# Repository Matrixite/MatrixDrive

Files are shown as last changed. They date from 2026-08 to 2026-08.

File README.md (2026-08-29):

# MatrixDrive



MatrixDrive started with a simple idea: make a Mega Drive/Genesis cartridge
that you can plug into a computer with USB-C, copy a game onto like a flash
drive, and then use in a real console.

Revision B takes that idea quite a bit further. It is also designed to run
Master System software on compatible Mega Drive hardware, supply ROM data to a
real 32X, work in the upper slot of Sonic & Knuckles, and keep supported save
data in battery-free FRAM.

- [Download the current source and prebuilt firmware package](https://github.com/Matrixite/MatrixDrive/raw/refs/heads/main/MatrixDrive_Dual_System_Cart_RevB_LockOn_Codemasters_64K_FRAM.zip)
- [Download the standalone KiCad project](https://github.com/Matrixite/MatrixDrive/raw/refs/heads/main/MatrixDrive_RevB_KiCad_Project.zip)

> [!IMPORTANT]
> MatrixDrive is still an engineering prototype. The software and logic have
> been tested, and the PCB has a preliminary fully connected route, but no
> physical cartridge has been built or tested in a console. Several package pin
> assignments still need to be verified and the board has not passed KiCad DRC.
> Please do not send the current PCB straight to a manufacturer.

## What MatrixDrive can do

| Mode | Files | Maximum size | What happens |
| --- | --- | ---: | --- |
| Mega Drive / Genesis | `.BIN`, `.MD`, `.GEN` | 4 MiB | The game is presented as linear cartridge ROM |
| 32X with real 32X hardware | `.32X` | 4 MiB | MatrixDrive supplies the ROM while the real 32X provides the 32X hardware |
| Sonic & Knuckles upper slot | Mega Drive images | 2 MiB recommended | Supports Sonic 2 lock-on and Sonic 3 with its dedicated save area |
| Master System | `.SMS` | 2 MiB | Uses either the Sega or Codemasters mapper selected by SW4 |

Master System mode should work on standard Mega Drive/Genesis Model 1 and Model
2 consoles. It will not work on an unmodified Genesis 3 or Sega Nomad because
their cartridge-port Master System mode pin is disconnected. The JVC X'Eye can
run SMS cartridges through an adapter, but its reset circuit prevents SMS games
from running from a Genesis flash cartridge such as MatrixDrive. Compatibility
with other all-in-one, portable, licensed, or clone systems has not yet been
verified. MatrixDrive also does not fit a standalone Master System cartridge
slot, and SMS mode cannot run through a 32X or the Sonic & Knuckles upper slot.

## How it works

When MatrixDrive is connected to a computer, it appears as a FAT16 drive called
`MATRIXDRV`. The RP2350B checks the game image and programs it into parallel NOR
flash. After USB is disconnected, the CPLD takes over and responds to the
console immediately, without waiting for the microcontroller to boot.

The main hardware is:

- an RP2350B for USB, file handling, validation, and flash programming;
- 32-Mbit x16 parallel NOR flash for predictable cartridge ROM reads;
- an ATF1508ASV CPLD for mode selection, address decoding, and SMS mapping;
- level translators and bus isolation for the 5 V console and 3.3 V logic;
- two FRAM devices providing 64 KiB of battery-free SMS save storage;
- a separate FRAM for the 8 KiB Sonic 3 lock-on save window;
- USB/console power isolation, status LEDs, SWD/UART, and test points.

## Loading a game

1. Remove MatrixDrive from the console, 32X, or lock-on cartridge.
2. Connect it to your computer with USB-C.
3. Open the `MATRIXDRV` drive, delete the old game, and copy over one supported
   image.
4. Safely eject the drive and wait for the green completion light.
5. Disconnect USB completely.
6. With all power off, select MD or SMS with SW2 and choose the required profile
   with SW4.
7. Insert the cartridge, then power on the console.

> [!WARNING]
> Never connect USB while MatrixDrive is fitted to a console, 32X, or Sonic &
> Knuckles cartridge. Never move SW2 or SW4 while powered, and never hot-plug any
> part of the cartridge stack.

## Switch settings

SW4 changes purpose depending on the position of SW2:

| SW2 | SW4 low | SW4 high |
| --- | --- | --- |
| MD | Linear ROM, 32X, or Sonic 2 lock-on | Linear ROM with Sonic 3 save FRAM |
| SMS | Sega mapper | Codemasters mapper |

Always change these switches with USB and console power disconnected.

## Sonic & Knuckles lock-on

For **Sonic 2 & Knuckles**, copy a normal Sonic 2 image, set SW2 to **MD**, and
set SW4 low to **LINEAR**. Power-of-two images up to 2 MiB are mirrored across
the upper-cartridge ROM window.

For **Sonic 3 & Knuckles**, copy a normal Sonic 3 image, set SW2 to **MD**, and
set SW4 high to **S3 SAVE**. MatrixDrive then maps the dedicated save FRAM over
odd-byte addresses `$200001-$203FFF` while leaving the rest of the ROM visible.

Read [Sonic & Knuckles lock-on mode](MatrixDrive_Dual_System_Cart_RevB/docs/sonic-knuckles-lock-on.md)
for the exact mapping, switch positions, and physical-fit checks.

## Using a real 32X

MatrixDrive is not trying to reproduce a 32X. A real 32X still supplies its
processors, boot ROM, registers, video, and audio hardware; MatrixDrive only
supplies the cartridge ROM.

Copy a `.32X` image, set SW2 to **MD**, leave SW4 low, disconnect USB, and fit
MatrixDrive to an unpowered 32X. The installer checks the `SEGA` header and
`MARS CHECK MODE` marker before accepting the image.

Do not use SW4 high for 32X software because that setting deliberately replaces
part of the ROM address range with the Sonic 3 save window. More detail is in
[32X cartridge mode](MatrixDrive_Dual_System_Cart_RevB/docs/32x-mode.md).

## Master System mapping and saves

| Profile | Mapper writes | Starting ROM banks | Save window |
| --- | --- | --- | --- |
| Sega | `$FFFC-$FFFF` | 0, 1, 2 | 16 KiB at `$8000-$BFFF` |
| Codemasters | `$0000`, `$4000`, `$8000` | 0, 1, 0 | 8 KiB at `$A000-$BFFF` |

In Codemasters mode, bit 7 of the `$4000` write enables FRAM and bits 2:0 choose
one of eight 8 KiB banks. This makes all 64 KiB of SMS save storage available
without hiding the ROM at `$8000-$9FFF`.

See [Master System mode](MatrixDrive_Dual_System_Cart_RevB/docs/master-system-mode.md)
for the full register and banking behaviour.

## Supported image rules

- Mega Drive/Genesis images must be normal big-endian ROMs, contain `SEGA` at
  offset `0x100`, and fit within 4 MiB.
- 32X images must use `.32X`, contain `SEGA` at `0x100` and `MARS CHECK MODE` at
  `0x3C0`, be a multiple of four bytes, and fit within 4 MiB.
- Lock-on images should be even-sized powers of two no larger than 2 MiB.
- Headerless SMS images need `TMR SEGA` at `0x1FF0`, `0x3FF0`, or `0x7FF0`.
- Interleaved `.SMD` files and copier headers are not supported.
- Only use game images that you are legally entitled to use.

No commercial ROM images are included in this repository.

## What has been tested

The project is automatically rebuilt and tested on every change. The passing
software-only tests currently cover:

- the FAT16 USB drive and ROM installer;
- Mega Drive, Master System, and 32X image validation;
- simulated NOR programming and ROM mirroring;
- Sega and Codemasters SMS mapper behaviour;
- Codemasters FRAM enabling and all eight save banks;
- Sonic 2/Sonic 3 lock-on mapping and the Sonic 3 save decoder;
- CPLD RTL simulation for MD, SMS, 32X ROM access, and lock-on modes;
- a complete RP2350B firmware build;
- a two-ROM emulator test that reached the combined Sonic 3 & Knuckles title
  screen and opening sequence.

These tests show that the intended software and logic paths behave correctly.
They cannot prove cartridge fit, signal timing, voltage translation, power
isolation, save retention, or operation on real Sega hardware.

## PCB status

The KiCad project contains a complete logical schematic and a preliminary
eight-layer PCB route. The routing report currently records all 188 routable
nets connected, using six signal layers plus dedicated ground and 3.3 V planes.

Before a board can be considered ready to build, it still needs:

- verified physical pin assignments and manufacturer footprints for the
  RP2350B, CPLD, NOR, translators, and FRAM devices;
- CPLD fitting, resource checks, and worst-case timing analysis;
- KiCad ERC/DRC after refilling the copper zones;
- USB differential-pair and signal/power-integrity review;
- cartridge-edge, PCB-thickness, bevel, shell, and insertion measurements;
- staged bench testing before it is connected to any console.

Only the Sonic 3 odd-byte save layout is implemented for Mega Drive software.
Generic Mega Drive or 32X SRAM/EEPROM saves, ROMs larger than 4 MiB,
enhancement hardware, unusual regional or game-specific SMS mappers, light-gun
support, and Sega mapper RAM-at-`$C000` mode are outside this revision.

Start with [Safety and bring-up](MatrixDrive_Dual_System_Cart_RevB/docs/safety-and-bringup.md)
before attempting any hardware test.

## Project layout

| Path | What you will find there |
| --- | --- |
| [`MatrixDrive_Dual_System_Cart_RevB/`](MatrixDrive_Dual_System_Cart_RevB/) | Main Revision B project |
| [`cpld/`](MatrixDrive_Dual_System_Cart_RevB/cpld/) | Mapper RTL, reference model, and testbench |
| [`firmware/`](MatrixDrive_Dual_System_Cart_RevB/firmware/) | RP2350B USB installer firmware |
| [`hardware/`](MatrixDrive_Dual_System_Cart_RevB/hardware/) | KiCad files, BOM, pinout, netlist, and routing report |
| [`docs/`](MatrixDrive_Dual_System_Cart_RevB/docs/) | Architecture, compatibility, and bring-up notes |
| [`tools/`](MatrixDrive_Dual_System_Cart_RevB/tools/) | Project generator, router, and validation scripts |

The [full design README](MatrixDrive_Dual_System_Cart_RevB/README.md) contains
the component-level details and additional design notes.

## Building and testing the project

You will need Python 3, the Raspberry Pi Pico SDK 2.3.0, an Arm GNU toolchain,
CMake/Ninja, and Icarus Verilog.

```sh
cd MatrixDrive_Dual_System_Cart_RevB
python3 tools/generate_kicad_project.py
python3 tools/route_kicad_pcb.py
python3 tools/validate_project.py
```

To build the RP2350B firmware:

```sh
export PICO_SDK_PATH=/absolute/path/to/pico-sdk
cmake -S firmware -B ../build/firmware -G Ninja \
  -DPICO_BOARD=matrixdrive \
  -DPICO_PLATFORM=rp2350-arm-s \
  -DCMAKE_BUILD_TYPE=Release
cmake --build ../build/firmware
```

## Technical references

- [Genesis Plus GX cartridge implementation](https://github.com/ekeeke/Genesis-Plus-GX/blob/master/core/cart_hw/md_cart.c)
- [Sega 32X Hardware Manual transcription](https://github.com/matiaszanolli/sega-vr-disasm/blob/master/docs/32x-hardware-manual.md)
- [Raspberry Pi RP2350 documentation](https://www.raspberrypi.com/documentation/microcontrollers/microcontroller-chips.html)
- [Microchip ATF1508ASV](https://www.microchip.com/en-us/product/atf1508asv)
- [Infineon FM18W08 FRAM](https://www.infineon.com/part/FM18W08-SG)
- [TI SN74LVC1T45](https://www.ti.com/product/SN74LVC1T45)

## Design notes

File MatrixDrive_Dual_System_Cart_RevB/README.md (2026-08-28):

# MatrixDrive Dual-System USB Cartridge — Revision B

MatrixDrive Revision B is a prototype USB-loadable Mega Drive/Genesis cartridge that can also supply ROM to a real 32X, run Master System software on compatible consoles, and act as the upper cartridge in Sonic & Knuckles lock-on mode. USB-C exposes a removable FAT16 drive named `MATRIXDRV`; after one ROM is copied and safely ejected, the RP2350B installs it into non-volatile parallel NOR.

Console reads never depend on RP2350 response time. Translators and an instant-on CPLD connect the console directly to NOR or the selected FRAM.

## Supported images

| Console mode | File | Active image limit | Cartridge hardware |
| --- | --- | ---: | --- |
| Mega Drive / Genesis | `.BIN`, `.MD`, `.GEN` | 4 MiB | Linear `$000000-$3FFFFF` ROM |
| 32X through a real 32X | `.32X` | 4 MiB | Linear x16 ROM with 4 MiB mask-ROM-style mirroring |
| Sonic & Knuckles upper slot | Mega Drive image | 2 MiB recommended | Mirrored ROM; optional Sonic 3 save profile |
| Master System | `.SMS` | 2 MiB | Sega or Codemasters mapper selected by SW4 |

Power-of-two Mega Drive images smaller than 2 MiB are repeated by the installer through the full 2 MiB lock-on window. This gives a 1 MiB Sonic 2 image the mirroring expected from its original mask ROM.

Power-of-two `.32X` images smaller than 4 MiB are repeated through the complete 32-Mbit cartridge space. The firmware requires the standard `SEGA` header at `0x100` and `MARS CHECK MODE` at `0x3C0`, then preserves every ROM byte—including the mandatory 32X security/startup area beginning at `0x3F0`.

For Sonic 3 & Knuckles, SW4's high position in MD mode enables a dedicated 8 KiB odd-byte FRAM window at `$200001-$203FFF`. This storage is physically separate from the two FM18W08 devices that supply the complete 64 KiB SMS save array.

SMS images are stored one byte per x16 NOR word. The CPLD implements Sega or Codemasters 16 KiB banking selected by SW4. Plain 8/16/32/48 KiB images and larger mapped images work.

## Normal use

1. Remove MatrixDrive from the console, 32X, or Sonic & Knuckles cartridge.
2. Connect USB-C, remove the previous image, and copy one supported ROM to `MATRIXDRV`.
3. Safely eject and wait for the steady green completion indication.
4. Disconnect USB and set SW2/SW4 while all hardware is unpowered.
5. Insert MatrixDrive directly into the console, into the real 32X cartridge slot for `.32X` use, or into the Sonic & Knuckles upper slot for MD lock-on use.
6. Power on. In SMS mode, use the cartridge PAUSE button when a game needs the Master System NMI pause input.

### Switch positions

| Use | SW2 | SW4 |
| --- | --- | --- |
| Normal Mega Drive or Sonic 2 & Knuckles | MD | Low: LINEAR |
| 32X cartridge through real 32X hardware | MD | Low: LINEAR |
| Sonic 3 & Knuckles with saves | MD | High: S3 SAVE |
| Sega-mapper SMS | SMS | Low: SEGA |
| Codemasters-mapper SMS | SMS | High: CODEMASTERS |

Never move either switch while powered. Never connect USB while MatrixDrive is inserted into a console, 32X, or another cartridge.

## 32X compatibility

MatrixDrive does not emulate a 32X. In this mode, the physical 32X supplies its dual SH2 processors, boot ROM, registers, video and audio hardware, while MatrixDrive behaves as the attached 4 MiB cartridge ROM. The 32X adapter performs its normal cartridge banking internally.

Use SW2=MD and SW4=LINEAR. SW4's S3 SAVE position is not compatible because it intentionally replaces odd-byte addresses `$200001-$203FFF` with FRAM. Generic 32X SRAM/EEPROM saves, images larger than 4 MiB, and special cartridge hardware are not implemented.

See `docs/32x-mode.md` for exact mapping and real-hardware bring-up requirements.

## Lock-on compatibility

The electrical profile follows the documented lock-on behaviour and the Genesis Plus GX implementation:

- Sonic & Knuckles supplies its own ROM at the lower 2 MiB and exposes the upper cartridge in the remaining window.
- MatrixDrive behaves as a normal MD ROM in the upper slot.
- The installer supplies mask-ROM-style mirroring for even-sized power-of-two images up to 2 MiB.
- The Sonic 3 save profile maps U20 to odd-byte addresses `$200001-$203FFF`.
- U19 translates the CPLD's high-byte-disable request into the 5 V domain so U7 is inactive during low-byte-only save cycles.
- Sonic & Knuckles owns its `$A130F0` lock-on control; MatrixDrive does not emulate the base lock-on cartridge.

See `docs/sonic-knuckles-lock-on.md` for exact use and remaining physical-fit validation.

## Image validation

- Mega Drive images require `SEGA` at byte offset `0x100`, normal big-endian byte order, and a maximum size of 4 MiB. Interleaved `.SMD` images are rejected.
- `.32X` images must be a multiple of four bytes, fit in 4 MiB, contain `SEGA` at `0x100`, and contain `MARS CHECK MODE` at `0x3C0`.
- Lock-on images should be even-sized powers of two no larger than 2 MiB.
- Headerless SMS images require `TMR SEGA` at `0x1FF0`, `0x3FF0`, or `0x7FF0`.
- Use only software you are legally entitled to use.

## Hardware summary

- RP2350B, USB Full-Speed Mass Storage, and a 16 MiB FAT16 staging flash.
- S29GL032N-compatible 32-Mbit x16 active parallel NOR.
- ATF1508ASV-15AU100 CPLD for instant-on mode, SMS mapping, and Sonic 3 save decode.
- U17/U18: two FM18W08 32 KiB x8 FRAMs, exactly 64 KiB for SMS saves.
- U20: dedicated FM18W08, with 8 KiB decoded for Sonic 3 lock-on saves.
- U19: SN74LVC1T45 translating the MD high-data-disable control to CART_5V.
- Dual-supply 5 V/3.3 V translation on every active cartridge signal.
- USB/console source isolation, PROGRAM and PAUSE buttons, and power-off selectors.

## Project contents

- `docs/architecture.md` — electrical and data-path architecture.
- `docs/master-system-mode.md` — SMS mapper and storage details.
- `docs/32x-mode.md` — real-32X cartridge mapping, switches, limits, and bring-up.
- `docs/sonic-knuckles-lock-on.md` — lock-on mapping, switches, fit, and limitations.
- `docs/safety-and-bringup.md` — mandatory staged test procedure.
- `hardware/bom.csv`, `connector-pinout.csv`, `electrical-netlist.csv` — connection authorities.
- `hardware/MatrixDrive-RevB.sch` — complete logical schematic; KiCad 8/9 converts it to native format on first save.
- `hardware/MatrixDrive-RevB.kicad_pcb` — native preliminary routed eight-layer PCB with the physical cartridge edge, six signal layers, and dedicated ground/3.3 V planes.
- `hardware/routing-report.json` — deterministic route completion counts, layer assignment, widths, and via dimensions.
- `hardware/README-KICAD.md` — project opening instructions and fabrication release gates.
- `cpld/matrixdrive_mapper.v` — synthesizable SMS and lock-on decoder RTL.
- `cpld/test_matrixdrive_mapper.v` — RTL mapper/FRAM testbench.
- `firmware/` — RP2350/Pico SDK firmware source.

## Engineering status

This is a **Revision B engineering prototype**, not a fabrication-ready or production-tested commercial cartridge. The PCB has a preliminary connectivity-complete route, but it has not passed KiCad DRC or physical review. Before fabrication, review and verify the logical schematic, assign and fit the CPLD, verify resources and timing, copy the official RP2350B minimal design, confirm exact package pin maps, review/refine the route, pass ERC/DRC, and measure the edge/shell against a normal donor cartridge, a real 32X cartridge slot, and a real Sonic & Knuckles upper slot.

Do not send the included KiCad PCB directly to fabrication. Complete the release gates in `hardware/README-KICAD.md` and `docs/safety-and-bringup.md` before any console test.

The repository root also contains `MatrixDrive_RevB_KiCad_Project.zip`, a
standalone copy of the schematic, board, symbol library, BOM and connection
authorities.

## Build prerequisites

- Raspberry Pi Pico SDK 2.3.0 and Arm GNU Toolchain.
- CMake plus Ninja or Make.
- Icarus Verilog for RTL simulation.
- KiCad 8 or later for schematic conversion, PCB editing, ERC and DRC.
- A verified ATF1508ASV fitting/JED programming flow.

The prototype USB descriptor uses TinyUSB's development VID `0xCAFE`. Obtain a proper VID/PID before distribution.

## Primary references

- Genesis Plus GX MD cartridge: <https://github.com/ekeeke/Genesis-Plus-GX/blob/master/core/cart_hw/md_cart.c>
- Genesis Plus GX SRAM: <https://github.com/ekeeke/Genesis-Plus-GX/blob/master/core/cart_hw/sram.c>
- Sega 32X Hardware Manual transcription: <https://github.com/matiaszanolli/sega-vr-disasm/blob/master/docs/32x-hardware-manual.md>
- TI SN74LVC1T45: <https://www.ti.com/product/SN74LVC1T45>
- RP2350: <https://www.raspberrypi.com/documentation/microcontrollers/microcontroller-chips.html>
- ATF1508ASV: <https://www.microchip.com/en-us/product/atf1508asv>
- FM18W08 FRAM: <https://www.infineon.com/part/FM18W08-SG>

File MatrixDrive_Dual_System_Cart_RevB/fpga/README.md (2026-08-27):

# Master System YM2413 FPGA option

This directory implements the optional MatrixDrive Master System FM path. It
adds a dedicated Lattice ECP5 FPGA beside the existing ATF1508 mapper; the
CPLD remains responsible for ROM and save mapping, while the FPGA implements
the YM2413, its I/O ports and the audio DAC.

This is an RTL-complete engineering option, not a retrofit for an assembled
Revision B PCB. The Revision B placement template has no FPGA, configuration
flash, FPGA power rails or audio filter. Integrate the logical netlist here
into a reviewed schematic and routed board spin before building hardware.

## Implemented behavior

| SMS port | Direction | FPGA behavior |
| --- | --- | --- |
| `F0` | Write | Latches the YM2413 register address |
| `F1` | Write | Writes data to the selected YM2413 register |
| `F2` | Read/write | Three-bit FM/detection register; reset read is `FF` |

F2 bit 0 enables the cartridge FM output. Bits 1 and 2 are stored and read
back for software compatibility. Bit 1 cannot mute the Mega Drive's internal
PSG from a cartridge, so software that relies on hardware PSG suppression may
sound different.

Every port decode includes `/IORQ`. In Mega Drive SMS mode, VA19 on the edge
connector becomes the Master System `/IORQ`; MatrixDrive already translates
that pin onto the `CART_A18` net. The FPGA top-level therefore receives it as
`cart_a18_iorq_n`. Do not replace this with address-only decoding.

## RTL data path

1. `sms_fm_bus.v` synchronizes F0/F1/F2 writes from the cartridge bus and
   generates clean write pulses for the OPLL core.
2. The BSD-licensed IKAOPLL core implements the cycle-accurate YM2413 signal
   path and produces a signed 16-bit accumulated sample.
3. `pdm_dac.v` converts that sample to a 14.31818 MHz one-bit stream.
4. A two-pole passive low-pass filter, AC coupling capacitor and separate
   injection resistors feed cartridge audio inputs SL1 and SR2.

The data bus is driven only for an F2 I/O read while SMS mode is selected and
USB is absent. It is high-impedance for normal memory cycles, MD mode and USB
programming.

## Clock and target

The reference target is `LFE5U-12F-6BG256C`. The top-level input is a dedicated
14.318180 MHz CMOS oscillator. A one-in-four clock enable supplies the OPLL
with the 3.579545 MHz phiM rate while all FPGA registers stay in one physical
clock domain.

Generic ECP5 synthesis reports approximately 1,347 LUT4s, 1,727 flip-flops,
103 carry cells and two 18x18 multipliers. This leaves substantial margin in a
12K device. Final utilization and timing must be rechecked after package-pin,
I/O-standard and board constraints are assigned.

For PAL pitch locked to the console's slower SMS clock, populate the
region-specific oscillator and change the top-level divide ratio/constraint
accordingly. The supplied 14.318180 MHz option intentionally produces the
original 3.579545 MHz YM2413 reference rate.

## Build and test

From this directory:

```sh
make test
make lint
make synth
```

`make test` needs Python 3 and Icarus Verilog. `make lint` and `make synth`
need Yosys with ECP5 support. Synthesis creates
`build/matrixdrive_sms_fm.json`.

The repository deliberately does not include a place-and-route constraint
file or bitstream. Package pins depend on the final schematic and PCB escape;
using invented assignments would be unsafe. Complete
`hardware/pin-assignment-template.csv`, add an LPF constraint file, run
nextpnr-ecp5, and close timing before programming a device.

## Hardware release gates

- Capture the FPGA, 1.1 V core, 2.5 V auxiliary, 3.3 V I/O/configuration and
  SPI-flash circuits from current Lattice reference documents.
- Recalculate the cartridge current budget and replace the existing 200 mA
  protection/regulator arrangement if measurements require it.
- Prove all FPGA pins are high-impedance during configuration, MD mode and USB
  programming. Add external gating if the chosen configuration mode cannot
  guarantee this.
- Scope VA19, `/LWR`, `/CAS0`, address and data on each supported console
  revision before relying on the timing assumptions.
- Verify the F2 read turnaround with U6 and prove NOR/FRAM output enables stay
  inactive during the I/O cycle.
- Measure the filtered output for DC, peak voltage and ultrasonic residue
  before connecting SL1/SR2. Tune the two injection resistors on real hardware.
- Validate with the YM2413 test ROM and several FM-capable games on NTSC and
  PAL console revisions.

See `hardware/fpga-addon-bom.csv`, `hardware/logical-netlist.csv` and
`hardware/pin-assignment-template.csv` for the schematic-level integration
authority.

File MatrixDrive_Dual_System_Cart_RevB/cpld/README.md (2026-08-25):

# CPLD logic

`matrixdrive_mapper.v` is the portable logic source for U13. It contains the
instant-on Mega Drive/32X linear pass-through, Sega SMS mapper, Codemasters SMS mapper,
64 KiB FRAM decode, and USB ownership isolation. No console transaction depends
on the RP2350.

The power-off SW4 selector drives `codemasters_mapper` low for Sega or high for
Codemasters. Sega writes are decoded only at `$FFFC-$FFFF`. Codemasters writes
are decoded only at `$0000`, `$4000`, and `$8000`; bit 7 of the `$4000`
value enables an 8 KiB FRAM window at `$A000-$BFFF`, with bits 2:0 selecting
one of eight FRAM banks.

Target: `ATF1508ASV-15AU100`, 3.3 V, TQFP-100. The device has 128
macrocells, but fit and timing are release gates. This prototype intentionally
does not include guessed package pin assignments. Create them only after
schematic placement so voltage, JTAG, clock-capable pins, output-enable
resources, routing and timing can be reviewed together.

Required flow before hardware release:

1. Import/translate the module into the selected ATF1508ASV-supported tool.
2. Assign every port to the reviewed U13 schematic symbol and JTAG header.
3. Constrain translated address/control input-to-memory output delays.
4. Confirm the device fits and archive equations, fitter report, timing report,
   JED file and checksum.
5. Run `python3 test_mapper_model.py` and the Icarus RTL testbench.
   The RTL test includes the highest word address in the 4 MiB 32X cartridge
   space as well as the SMS and Sonic 3 save profiles.
6. Simulate the fitted equations and test a programmed device on a
   current-limited cartridge-slot breakout.

The USB-mode tri-states require external inactive pulls on NOR/FRAM controls
and FRAM address lines A13/A14. Do not rely on CPLD power-up values for bus
safety.

Device page: <https://www.microchip.com/en-us/product/atf1508asv>

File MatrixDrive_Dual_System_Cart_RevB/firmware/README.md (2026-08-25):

# Firmware

The firmware uses the Raspberry Pi Pico C/C++ SDK and TinyUSB. It targets the
RP2350B package because the parallel ROM bus consumes GPIO0 through GPIO39 and
the QFN-80 device supplies GPIO40 through GPIO47 for staging flash, sensing and
indicators.

## Build

```sh
export PICO_SDK_PATH=/absolute/path/to/pico-sdk
cmake -S . -B build -DPICO_BOARD=matrixdrive
cmake --build build
```

The output is `build/matrixdrive.uf2` plus ELF, BIN and HEX files. Fit the board's
SWD header for the first load; later firmware can also be loaded through the
RP2350 boot ROM when the hardware exposes its boot-select condition.

## Source layout

- `main.c` selects console-safe or USB programming operation.
- `msc_disk.c` implements the TinyUSB Mass Storage callbacks.
- `spi_nor.c` provides a 4 KiB cached block device on the staging flash.
- `fat16.c` formats and scans the staging volume without a dynamic allocator.
- `parallel_nor.c` programs and verifies the S29GL032N-compatible active ROM.
- `rom_installer.c` validates and streams a selected ROM into the active flash,
  packing MD/32X images x16 and SMS images one byte per word. Explicit `.32X`
  files also require the standard header/security marker and are mirrored
  through the complete 4 MiB cartridge range when appropriate.
- `usb_descriptors.c` defines a single Full-Speed MSC interface.

## Important implementation note

This is first-pass prototype firmware and has not been executed on the custom
board. Compile warnings should be treated as errors, and the active-NOR command
set must be checked against the exact suffix of the fitted flash before running
an erase or program operation. Keep the hardware write-enable pullup fitted
during all early tests. Firmware does not move the physical MD/SMS switch; set
SW2 only while the board is unpowered.

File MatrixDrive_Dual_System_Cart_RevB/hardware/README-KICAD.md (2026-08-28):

# MatrixDrive Revision B KiCad project

This directory now contains a complete logical engineering capture for the
MatrixDrive cartridge and a native KiCad 8 PCB with the same component and net
model.

## Open the project

1. Open `MatrixDrive-RevB.sch` in KiCad 8 or 9 Eeschema.
2. Accept KiCad's conversion prompt, then save it as
   `MatrixDrive-RevB.kicad_sch` beside the existing project file.
3. Open `MatrixDrive-RevB.kicad_pcb` in PCB Editor.
4. Refill all zones with `B`, then run **Inspect > Design Rules Checker**. Do
   not waive errors until the logical footprints below have been replaced.

The schematic is supplied in KiCad's readable legacy format because the
automated build environment does not contain Eeschema. `MatrixDrive_RevB.lib`
and `sym-lib-table` make the custom logical symbols self-contained. The board
file and `MatrixDrive-RevB.kicad_pro` are native KiCad 8 files.

## Captured circuitry

- 64-contact Mega Drive/Genesis cartridge edge and every used signal;
- USB-C UFP power, CC resistors, ESD protection and USB data path;
- diode-OR power isolation, fuse, 3.3 V regulator and RP2350 support rails;
- RP2350B GPIO mapping, boot QSPI, staging SPI flash, SWD/UART and indicators;
- 32-Mbit x16 active NOR ROM;
- five address/control translators, two data translators and isolation logic;
- ATF1508ASV mapper interface, JTAG and all RTL-visible signals;
- Sega/Codemasters SMS mapper controls and 64 KiB FRAM;
- Sonic 3 lock-on save FRAM and upper-byte disable path;
- MD/SMS, Pause and profile switches plus open-drain cartridge controls;
- pull-ups, pull-downs, decoupling and 22 named diagnostic test points.

The generated model currently contains 143 component references, 777 logical
pins and 192 named nets. `kicad-project-manifest.json` records these counts and
the outstanding release gates.

## PCB status

The PCB has the 100 mm x 65 mm engineering outline, physical 2x32 cartridge
edge, all component references, assigned pad nets, preliminary placement and a
connectivity-complete deterministic route. The eight-layer stack uses F.Cu,
In2.Cu, In3.Cu, In4.Cu, In5.Cu and B.Cu for signals, with uninterrupted GND on
In1.Cu and 3V3 on In6.Cu. `routing-report.json` records 188 of 188 routable nets
complete, 3,917 segments and 1,246 vias.

This route is a DRC handoff, not a fabrication release. It has not been opened
or checked by KiCad in the automated environment, USB is not yet
length/impedance controlled, and no signal-integrity or power-integrity review
has been done.

The programmable-device and memory symbols use logical, alphanumeric pad names
until the exact physical package maps have been approved. Those footprints are
marked `UNVERIFIED` or `LOGICAL`. They prevent this engineering capture from
being mistaken for a fabrication-ready board.

Before fabrication:

1. replace the U1, U2, U13, translator and FRAM logical footprints with verified
   manufacturer/package footprints;
2. assign and fit every ATF1508ASV pin, then close CPLD timing;
3. copy the current official RP2350B minimal-design power and QSPI pin mapping;
4. confirm NOR reset, write-protect and byte-mode strap polarity;
5. review/refine the preliminary bus route and route USB as a controlled 90-ohm differential pair;
6. review power integrity, translator direction/OE timing and cartridge loading;
7. refill zones and pass KiCad ERC, DRC and connectivity inspection;
8. complete the staged checks in `../docs/safety-and-bringup.md`.

Do not order PCBs from the generated board in its current state.

## Regeneration

Run:

```sh
python3 tools/generate_kicad_project.py
python3 tools/route_kicad_pcb.py
```

The older `generate_kicad_pcb.py` command is retained as a compatibility
wrapper and generates the same complete project.

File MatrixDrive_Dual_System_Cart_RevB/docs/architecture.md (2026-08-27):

# Architecture

## Console data paths

The console does not read through the RP2350. Translators convert the 5 V cartridge bus to 3.3 V, and the instant-on CPLD selects ROM or FRAM.

```text
MD/32X mode:  cartridge bus -> translators -> CPLD -> x16 NOR
S3 save:      odd byte  -> low translator -> CPLD -> dedicated x8 FRAM
SMS mode:     Z80 bus   -> translators -> CPLD mapper -> NOR low byte
                                      write/save tap -> 2 x x8 SMS FRAM
SMS FM spin:  VA19 /IORQ + F0/F1/F2 -> ECP5 YM2413 -> PDM filter -> SL1/SR2
USB mode:     USB-C -> RP2350B -> staging SPI NOR -> active parallel NOR
```

`hardware/electrical-netlist.csv` is the signal connection authority. This description is not a substitute for a reviewed schematic.

## Power and isolation

- Edge contacts A2/A31 feed `CART_5V` through F1; USB VBUS is separate.
- D1 and D2 diode-OR the sources into `SYS_5V`; U11 produces `3V3`.
- Cartridge-facing translator ports use `CART_5V` and become high impedance during USB-only operation.
- `BUS_DISABLE` is forced high when USB VBUS and console power coexist.
- `USB_MODE_3V3` tells U13 to release all shared NOR and FRAM controls.
- ROM and every FRAM chip enable have passive inactive pullups.
- U19 uses VCCA=3V3, VCCB=CART_5V, fixed A-to-B direction, Ioff, and VCC isolation to carry the Sonic 3 high-byte-disable request safely into U15.
- Both gates in U15 are used: the first combines bus/SMS isolation and the second adds the MD odd-byte save-cycle request.

## Mega Drive and lock-on mode

With SW2 in MD, `/M3`, VA21, and VA22 float. U13 normally passes translated VA1-VA21 to NOR A0-A20, `/CE_0` to `/CE`, and `/CAS0` to `/OE`. The x16 path returns VD0-VD15.

SW4 low selects the ordinary linear profile. It is also the Sonic 2 lock-on profile. Firmware repeats even-sized power-of-two MD images smaller than 2 MiB until the 2 MiB upper-cartridge window is filled.

SW4 high selects the Sonic 3 save profile:

- CPU odd-byte addresses `$200001-$203FFF` correspond to word addresses `$100000-$101FFF` on `cart_a`.
- U13 disables NOR and selects U20 only inside that range while `/CE_0` is active.
- U20 A0-A12 follow the cartridge word address; A13/A14 are grounded.
- `/CAS0` and `/LWR` become the shared FRAM OE/WE strobes.
- `md_high_disable` passes through U19 and U15 to disable U7, preventing the unused high byte from being driven during x8 FRAM access.
- U17/U18 remain inactive, keeping all 64 KiB of SMS save storage separate.

Sonic & Knuckles owns its `$A130F0` mapping control and supplies the lower cartridge ROM. MatrixDrive behaves only as the normal cartridge inserted in the upper slot.

## 32X cartridge mode

A physical 32X reads its inserted cartridge from both the Mega Drive/Genesis
68000 side and the SH2 side. The adapter owns its bank register and bus
arbitration; MatrixDrive remains a simple x16 ROM.

With SW2=MD and SW4=LINEAR, U13 passes the complete 21-bit word address to the
4 MiB NOR. The highest cartridge byte pair at `$3FFFFE-$3FFFFF` is word address
`$1FFFFF`. The 32X startup/security area is stored byte-for-byte and is not
interpreted by the CPLD.

SW4=S3 SAVE must not be used with 32X images because it replaces part of the
linear ROM range with U20. See `32x-mode.md`.

## Master System mode

With power off, SW2 is moved to SMS. Open-drain FETs pull `/M3`, VA21, and VA22 low. U13 then:

- uses translated VA1-VA16 as Z80 A0-A15;
- observes mapper writes through the low-byte bidirectional translator;
- maps three 16 KiB ROM slots using the SW4 profile;
- decodes Sega writes at `$FFFC-$FFFF` or exact Codemasters writes at `$0000/$4000/$8000`;
- uses `/CE_0` for `$0000-$7FFF` and `/CAS2` for `$8000-$BFFF`;
- drives only VD0-VD7;
- decodes 32 KiB Sega saves or banked 64 KiB Codemasters saves.

SW3 pulls the PAUSE/NMI contact low through an open-drain FET. See `master-system-mode.md`.

The optional FPGA spin taps translated A0-A7, D0-D7, `/LWR`, `/CAS0`, reset,
SMS/USB mode, and `CART_A18`. VA19 becomes `/IORQ` only in SMS mode, so
`CART_A18` is the mandatory I/O-cycle qualifier. The ECP5 never participates
in ROM or save mapping and drives MEM_D0-D7 only for an exact F2 I/O read.

The FPGA uses a dedicated 14.318180 MHz oscillator, a one-in-four phiM clock
enable, the IKAOPLL YM2413 core, and a one-bit PDM output. A passive two-pole
filter plus DC blocking and left/right series resistors inject mono FM into
SL1 and SR2. The FPGA option's separate logical connection authority is
`../fpga/hardware/logical-netlist.csv`.

## USB storage and installation

The RP2350 QSPI flash is dedicated to firmware. A separate 16 MiB SPI NOR backs a FAT16 superfloppy named `MATRIXDRV`. On safe eject, firmware validates one image, erases active NOR, and verifies each programmed word.

- MD bytes are packed big-endian: bytes 0/1 become flash D15:8/D7:0.
- 32X images use the same big-endian x16 packing; smaller power-of-two images repeat through 4 MiB.
- Even-sized power-of-two MD images below 2 MiB repeat through the 2 MiB lock-on window.
- SMS bytes use one x16 word each: D15:8 is `0xFF` and D7:0 is the ROM byte.

The same 4 MiB x16 NOR therefore holds either 4 MiB of MD/32X data or 2 MiB of SMS byte data.

## Programming ownership

RP2350 GPIO0-GPIO39 share the NOR-side bus and remain inputs without USB. With USB present, U13 releases shared outputs and the cartridge translators isolate before firmware drives those GPIOs. External pulls hold NOR, U17, U18, and U20 inactive during reset and handover. The RP2350 does not currently expose FRAM contents through USB.

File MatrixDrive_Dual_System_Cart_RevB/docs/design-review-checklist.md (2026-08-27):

# Design review checklist before routing

Revision B intentionally stops before a fabrication release. Close every item
below in the final schematic and PCB review.

## RP2350B subsystem

- Import the **current RP2350B Minimal KiCad** reference from Raspberry Pi's
  Product Information Portal; do not redraw the on-chip buck regulator from
  memory.
- Copy the complete VREG, DVDD/1V1, IOVDD, ADC_AVDD, USB_OTP_VDD, RUN, crystal,
  boot-flash and decoupling circuits.
- Preserve the official inductor orientation, output-capacitor placement and
  current return path. Use the specified polarised Abracon inductor unless the
  current hardware guide approves a substitute.
- Confirm every QFN-80 power and ground pin plus the exposed pad.
- Confirm external QSPI routing and boot-straps for the exact W25Q16 package.
- Run the latest Pico SDK board-header checks with `PICO_RP2350A=0`.

Official source: <https://pip.raspberrypi.com/categories/1214-rp2350>

## Cartridge interface

- Compare all 64 pad numbers with a known-good donor PCB and continuity-test a
  cartridge-slot breakout.
- Confirm that the KiCad front copper is the console-facing B row and back copper
  is the A row for the selected physical orientation.
- Verify hard-gold thickness, 1.6 mm board thickness, edge bevel and insertion
  depth with the intended manufacturer.
- Measure insertion, removal, door travel, component clearance and contact wipe
  in a real 32X cartridge slot as well as direct-console and lock-on slots.
- Simulate or measure 90 ns NOR access plus translator and CPLD delay against
  `/CE_0`, `/CAS0`, and `/CAS2` at minimum and maximum supply voltage.
- Capture real 32X SH2/68000 cartridge read timing at low and high ROM addresses
  and confirm the adapter's wait states cover the complete data-path delay.
- Confirm translator DIR straps and `BUS_DISABLE` default state with both power
  sources in every sequence.
- Fit an ATF1508ASV programming coupon first, assign all TQFP-100 pins, and
  archive the compiler fit/timing report and programmed JED checksum.
- Prove CPLD outputs release before RP2350 programming ownership and that
  passive pulls keep NOR/FRAM `/CE`, `/OE`, and `/WE` inactive during reset.
- Verify SW2 is break-before-make and asserts `/M3`, VA21 and VA22 through
  open-drain devices only; never source 3.3 V into those cartridge nets.
- Verify SW4 is labelled SEGA/CODEMASTERS, is sampled as a 3.3 V CPLD input,
  and cannot float during break-before-make travel.
- Measure U16/U6 direction turnaround around `/LWR` and prove the console, NOR,
  either FRAM and translator never drive D7:D0 simultaneously.
- Verify U17/U18 never assert together and exercise all eight Codemasters 8 KiB
  FRAM banks through logical addresses `$0000-$FFFF`.
- Check unused console inputs are not accidentally driven.

## Optional YM2413 FPGA spin

- Complete every item in `../fpga/README.md`; Revision B cannot be retrofitted
  merely by loading FPGA RTL.
- Capture the current ECP5 power, sysCONFIG, JTAG, oscillator and decoupling
  circuits in the reviewed schematic. Do not assign package pins from the
  logical template without completing BGA escape and bank-voltage review.
- Constrain the 14.318180 MHz clock, run place-and-route, close timing, archive
  the exact bitstream hash, and verify configuration completes safely.
- Prove ECP5 bus pins are high-impedance while unconfigured, in MD mode, with
  USB present, and during all non-F2 cycles.
- Scope VA19 as `/IORQ` on every intended console revision and verify F0/F1
  writes and F2 reads/writes cannot collide with NOR or FRAM.
- Recalculate the 3.3 V rail, 1.1 V/2.5 V regulators, inrush and cartridge
  fuse from post-route power estimates and measured current.
- Measure the PDM filter response, DC leakage, ultrasonic residue and peak
  voltage before fitting SL1/SR2 injection resistors.
- Run a YM2413 diagnostic and FM-capable games, including rhythm mode and F2
  enable/disable behavior, on NTSC and PAL targets.

## USB and power

- Route D+/D- as a short 90-ohm differential pair over an uninterrupted ground
  reference, with the ESD device at the receptacle.
- Verify separate 5.1 kOhm Rd resistors on CC1 and CC2.
- Measure reverse leakage through both source-isolation diodes.
- Verify the resettable fuse value against measured console-mode current.
- Prove that USB-only operation leaves A2/A31 and every other edge contact
  unpowered/high impedance.

## Storage and firmware

- Confirm the exact staging-flash JEDEC ID or relax the whitelist only after
  testing a substitute.
- Power-cycle during writes to evaluate FAT and erase-cache recovery.
- Test Windows, macOS and Linux safe-eject behaviour.
- Test fragmented files and root directories containing unrelated files.
- Test minimum, maximum, odd-length and invalid-header images.
- Test `.32X` images at 1, 2 and 4 MiB, invalid `MARS CHECK MODE` data, and the
  highest byte pair at `$3FFFFE-$3FFFFF`.
- Test `.SMS` images at 8 KiB, 32 KiB, 48 KiB and 2 MiB in both SW4 positions.
- Exercise every Sega register, the fixed 1 KiB window, both Sega FRAM halves,
  all three Codemasters bank registers and all eight Codemasters FRAM banks.
- Reserve a real USB VID/PID before any public product release.

## Release gates

- ERC clean with reviewed exceptions.
- DRC clean with a documented manufacturer rule set.
- Four-layer stack-up and impedance quotation approved.
- Current-limited breakout test passed.
- Logic-analyser timing capture archived.
- At least one Model 1 and one Model 2 console tested with homebrew diagnostics.
- Real 32X tested with a ROM-only diagnostic, followed by multiple legally
  obtained cartridge images covering different ROM sizes and regions.
- Master System mode tested on each intended console revision, including reset,
  Pause NMI and a save/load/power-cycle cycle.

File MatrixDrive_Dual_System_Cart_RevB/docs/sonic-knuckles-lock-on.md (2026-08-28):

# Sonic & Knuckles lock-on mode

## Scope

MatrixDrive is designed to behave as the ordinary Mega Drive/Genesis cartridge inserted into the upper slot of an original Sonic & Knuckles cartridge. It does not replace or emulate the Sonic & Knuckles base cartridge.

This profile targets:

- Sonic 2 & Knuckles from a normal Sonic 2 image;
- Sonic 3 & Knuckles from a normal Sonic 3 image;
- the normal Blue Sphere response that Sonic & Knuckles produces for other simple ROM cartridges.

SMS mode, unusual MD mappers, serial EEPROM cartridges, enhancement hardware, and carts larger than 2 MiB are not supported through the lock-on path in this revision.

## Why ROM mirroring is required

Sonic & Knuckles exposes the upper cartridge in a 2 MiB window. A physical small mask ROM naturally repeats when unimplemented high address pins are absent. MatrixDrive uses a 4 MiB NOR, so firmware must reproduce that behaviour.

During installation, an MD image is repeated through 2 MiB when all of these are true:

- the file is smaller than 2 MiB;
- its size is a power of two;
- its size is even;
- it has passed the normal MD header validation.

A normal 1 MiB Sonic 2 image is therefore written twice. A 2 MiB Sonic 3 image needs no extra copy. The original source file on `MATRIXDRV` is unchanged.

## Sonic 3 save window

Sonic 3 & Knuckles accesses the save memory from the upper cartridge at odd-byte addresses `$200001-$203FFF`. On the cartridge word-address bus this is `$100000-$101FFF`.

With SW2=MD and SW4 high:

| Signal or device | Behaviour |
| --- | --- |
| U2 NOR | Disabled inside the save window |
| U20 | Selected for exactly 8 KiB using A0-A12 |
| U17/U18 | Disabled; SMS saves remain separate |
| U6 low data | Carries D0-D7 reads and writes |
| U7 high data | Disabled by U13 → U19 → U15 |
| Read strobe | `/CAS0` drives shared FRAM `/OE` |
| Write strobe | `/LWR` drives shared FRAM `/WE` |

U20 is a 32 KiB FM18W08 for component consistency and availability, but A13/A14 are grounded and only 8 KiB is visible. Its remaining capacity is intentionally inaccessible.

## Switch settings

| Game/result | SW2 | SW4 |
| --- | --- | --- |
| Sonic 2 & Knuckles | MD | Low: LINEAR |
| Sonic 3 & Knuckles with save support | MD | High: S3 SAVE |
| Other simple lock-on cartridge / Blue Sphere | MD | Low: LINEAR |

SW4 remains the Sega/Codemasters selector when SW2 is in SMS mode. Move both switches only with console and USB power absent.

## Loading and stacking

1. Remove MatrixDrive from all console hardware.
2. Connect USB-C and install a legal, clean big-endian Sonic 2 or Sonic 3 image.
3. Safely eject, wait for the steady green indication, and disconnect USB.
4. Set SW2/SW4 using the table above.
5. Insert MatrixDrive fully into the Sonic & Knuckles upper slot without rocking it.
6. Insert Sonic & Knuckles into the powered-off console.
7. Power on.
8. Power off and remove the complete stack before reconnecting USB or moving a switch.

## Physical requirements

The electrical design uses the standard 64-contact Mega Drive/Genesis edge. Physical lock-on compatibility also depends on details that cannot be proven by the preliminary routed engineering layout:

- PCB thickness and bevel;
- finger plating, pitch, and insertion depth;
- board and shell width;
- component height below the upper-slot door;
- switch and USB-C clearance;
- retention and extraction forces.

Measure a real Sonic & Knuckles cartridge and a known-good upper cartridge before finalising the board outline and shell. Do not fabricate the current template as-is.

## Validation gates

Before connecting to Sonic & Knuckles:

- pass direct-console MD tests;
- verify the 2 MiB mirror pattern in NOR;
- sweep the U20 decode boundaries with a cartridge breakout;
- verify U7 is disabled during every U20 cycle;
- confirm U20 does not overlap U17/U18;
- fit and time the exact ATF1508ASV equations;
- confirm the complete stacked assembly is mechanically stable;
- monitor current on the first lock-on power-up.

Automated tests prove the source-level decode and installer pattern. They do not prove CPLD fit, analogue timing, connector wear, or real-cartridge operation.

## Primary implementation references

- [Genesis Plus GX Mega Drive cartridge and lock-on handling](https://github.com/ekeeke/Genesis-Plus-GX/blob/master/core/cart_hw/md_cart.c)
- [Genesis Plus GX backup RAM mapping](https://github.com/ekeeke/Genesis-Plus-GX/blob/master/core/cart_hw/sram.c)

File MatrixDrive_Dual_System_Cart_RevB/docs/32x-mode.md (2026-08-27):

# 32X cartridge mode

## Scope

MatrixDrive can supply a cartridge ROM to a physical Sega 32X. It does not
emulate the 32X: the real adapter still provides the two SH2 processors, boot
ROM, security check, registers, video hardware, audio hardware, and cartridge
arbitration.

The 32X hardware maps a 32-Mbit cartridge space and can read the cartridge from
both its SH2 side and the Mega Drive/Genesis 68000 side. MatrixDrive's existing
4 MiB x16 NOR and MD linear CPLD path match that cartridge-ROM width and size.

## Image installation

Use a clean, normal big-endian `.32X` image no larger than 4 MiB. The installer
requires:

- file size of at least `0x400` bytes and no more than 4,194,304 bytes;
- a size divisible by four, as required by the 32X startup data layout;
- `SEGA` at byte offset `0x100`;
- `MARS CHECK MODE` at byte offset `0x3C0`.

The last check distinguishes an explicit `.32X` image from an ordinary Mega
Drive image and protects against programming an image without the expected 32X
startup/security area. The firmware does not patch this data. Every source byte
is written to parallel NOR in its original order.

When a `.32X` image is an exact power of two smaller than 4 MiB, the installer
repeats it through the complete 4 MiB active NOR. This reproduces the way a
smaller mask ROM appears when the 32X drives address pins that the original ROM
did not implement.

## Switches and physical stack

| Item | Required setting |
| --- | --- |
| SW2 | MD |
| SW4 | Low: LINEAR |
| USB | Disconnected |
| Stack | MatrixDrive -> real 32X -> Mega Drive/Genesis |

SW4 high is not a 32X profile. In MD mode it enables the Sonic 3 odd-byte FRAM
window at `$200001-$203FFF`, which would replace part of the 32X ROM and prevent
correct operation.

Power off the complete stack before insertion or removal. Do not place Sonic &
Knuckles between MatrixDrive and the 32X. Do not connect USB while MatrixDrive is
inserted into the 32X.

## What is implemented

- Standard 4 MiB linear x16 cartridge ROM.
- Explicit `.32X` FAT16 discovery and validation.
- Byte-for-byte preservation of the 32X header and security/startup code.
- Full 4 MiB mirroring for smaller power-of-two images.
- CPLD pass-through through the highest cartridge word address (`$3FFFFE`).

## Limits

- No generic 32X SRAM or EEPROM save emulation.
- No ROM images larger than 4 MiB.
- No special mapper, coprocessor, or enhancement cartridge hardware.
- Physical fit, voltage levels, bus timing, boot/security completion, and game
  operation have not yet been measured on a real 32X.

Games that depend on unsupported cartridge save memory may boot but cannot be
expected to save correctly. Use a ROM-only diagnostic or game for the first
hardware test.

## First real-32X test

Complete the USB-only, simulated-console, and direct Mega Drive tests in
`safety-and-bringup.md` first.

1. Inspect and clean the MatrixDrive and 32X cartridge contacts.
2. Install a legally obtained, known-good ROM-only `.32X` diagnostic or game.
3. Verify SW2=MD and SW4=LINEAR with all power removed.
4. Insert MatrixDrive into the unpowered 32X, then install the 32X normally.
5. Power the stack through a current monitor and stop for abnormal current,
   heat, or out-of-rail signals.
6. Capture cartridge `/CE_0`, `/CAS0`, address, and data timing at the start,
   middle, and top of the ROM range.
7. Confirm the 32X security/startup sequence completes and the program reaches
   its first interactive screen.
8. Power off and remove the complete stack before reconnecting USB.

## References

- [Sega 32X Hardware Manual transcription](https://github.com/matiaszanolli/sega-vr-disasm/blob/master/docs/32x-hardware-manual.md)
- [32X ROM identification in file(1)](https://github.com/file/file/blob/master/magic/Magdir/console)

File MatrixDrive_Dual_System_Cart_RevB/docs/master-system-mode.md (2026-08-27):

# Master System mode

## Scope

Revision B targets Master System software running through a Mega Drive/Genesis
cartridge slot, similar to the electrical role of a Power Base Converter. It is
not a physical Master System cartridge and requires a console revision that
still exposes and supports SMS mode.

Implemented:

- 8/16/32/48 KiB fixed/no-mapper ROMs;
- Sega mapper ROMs through 2 MiB;
- Codemasters mapper ROMs through 2 MiB;
- power-off Sega/Codemasters mapper selector;
- 64 KiB non-volatile FRAM shared by both mapper profiles;
- physical Pause/NMI button;
- optional FPGA YM2413 with `F0`/`F1` writes, `F2` detection and cartridge audio output.

Not implemented: Korean, multicart or game-specific mappers;
light-gun accessory circuitry; Mega Drive save hardware; Sega mapper bit 4
RAM-at-`$C000` mode. These require a later verified CPLD profile.

The FM option requires a new board spin and is not present on the Revision B
placement template.

## Power-off mapper selector

SW4 selects the SMS mapper profile. Move it only when console and USB power are
absent.

| SW4 position | Mapper writes | Reset ROM banks | Save window |
| --- | --- | --- | --- |
| Sega | `$FFFC-$FFFF` | 0, 1, 2 | 16 KiB at `$8000-$BFFF` |
| Codemasters | exact `$0000`, `$4000`, `$8000` | 0, 1, 0 | 8 KiB at `$A000-$BFFF` |

The selector is a hardware input to U13. Firmware does not auto-detect the
mapper and console transactions never wait for the RP2350.

## Sega mapper

U13 resets the control register to `0` and the three ROM banks to 0, 1, and 2.
Writes are captured at the rising edge of translated `/LWR`:

| Address | Register | Effect |
| --- | --- | --- |
| `$FFFC` | control | bit 3 enables FRAM; bit 2 selects FRAM half |
| `$FFFD` | page 0 | ROM bank for `$0000-$3FFF`, except fixed first 1 KiB |
| `$FFFE` | page 1 | ROM bank for `$4000-$7FFF` |
| `$FFFF` | page 2 | ROM bank for `$8000-$BFFF` |

Only bank bits 6:0 reach NOR A20:A14, matching the 2 MiB `.SMS` limit. Sega
FRAM uses the lower 32 KiB of the installed 64 KiB: A13 follows the CPU
address, A14 follows control bit 2, and the low FRAM chip is selected.

## Codemasters mapper

U13 resets the three ROM banks to 0, 1, and 0. There is no Sega-style fixed
first-1-KiB window.

| Write address | Effect |
| --- | --- |
| `$0000` | Select 16 KiB ROM bank for `$0000-$3FFF` |
| `$4000`, bit 7 clear | Disable FRAM and select ROM bank for `$4000-$7FFF` |
| `$4000`, bit 7 set | Enable FRAM; bits 2:0 select one of eight 8 KiB banks |
| `$8000` | Select 16 KiB ROM bank for `$8000-$BFFF` |

When FRAM is enabled, only `$A000-$BFFF` is replaced. ROM remains readable at
`$8000-$9FFF`, and enabling FRAM preserves the previous slot-1 ROM bank. The
three FRAM bank bits become logical A15:A13. Two 32 KiB FM18W08 devices provide
the exact 64 KiB array; U13 drives separate active-low chip enables for the low
and high halves.

The Codemasters behaviour matches the reset and banking implementation in
[Genesis Plus GX](https://github.com/ekeeke/Genesis-Plus-GX/blob/master/core/cart_hw/sms_cart.c).

## FPGA YM2413 option

In SMS mode, Mega Drive cartridge edge signal VA19 becomes the Z80 `/IORQ`.
Revision B already translates VA19 as `CART_A18`; the FPGA spin taps that net
along with A0-A7, D0-D7, `/LWR`, `/CAS0`, reset and the mode signals.

| I/O port | Behavior |
| --- | --- |
| `F0` | Write YM2413 register address |
| `F1` | Write YM2413 register data |
| `F2` | Read/write the three-bit FM/detection register |

The F2 register resets to `111`; reads return `11111xxx`. Bit 0 enables FM
audio. Bits 1 and 2 are stored for compatibility, but a cartridge cannot mute
the Mega Drive's internal PSG, so bit 1 is not able to reproduce that system-
level function.

F0 and F1 are forwarded to the cycle-accurate IKAOPLL core. Its signed output
feeds a one-bit PDM DAC, a two-pole low-pass filter, AC coupling, and separate
SL1/SR2 injection resistors. The FPGA bus pins are high-impedance in MD mode,
with USB present, and on every cycle other than an exact F2 I/O read.

See `../fpga/README.md` for RTL, clocking, synthesis, licensing and hardware
release gates.

## NOR representation

The installer writes SMS byte `n` to NOR word address `n` as
`0xFF00 | byte`. In SMS mode only D7:D0 are returned to the console. In MD
mode the same device is read normally as an x16 array. Installing a ROM replaces
the previous active image but does not erase FRAM.

## Physical mode and pause

SW2 must be a break-before-make slide switch and may only be moved with console
and USB power absent. It supplies `SMS_MODE_3V3` to the CPLD and enables
open-drain pulls on `/M3`, VA21 and VA22. Never drive those 5 V cartridge nets
directly from 3.3 V logic.

SW3 drives VA23 only through open-drain Q4. It is ignored in MD mode. Mount all
controls where they cannot contact the cartridge shell or move during insertion.

## Timing constraints

The CPLD address mux plus translator plus NOR/FRAM access must fit the SMS read
and write windows at worst-case voltage and temperature. Archive fitted-CPLD
timing plus oscilloscope/logic-analyser captures for both mapper profiles,
FRAM reads/writes, reset defaults, selector states and Pause NMI.

For the FPGA spin, also archive captures of F0/F1/F2 I/O cycles showing VA19
`/IORQ`, `/LWR` or `/CAS0`, address, data and FPGA output enable. Verify F2
turnaround through U6, confirm NOR/FRAM remain inactive, and measure filtered
audio amplitude and ultrasonic residue at both SL1 and SR2.

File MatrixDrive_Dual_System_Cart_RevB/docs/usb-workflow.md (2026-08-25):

# USB workflow and indicators

## Drive behaviour

The staging volume appears as `MATRIXDRV`. It accepts one root-level `.BIN`,
`.MD`, `.GEN`, `.32X`, or `.SMS` file. Subdirectories, `.SMD`, copier-headered SMS
images and files for unsupported mappers are ignored or rejected.

After copying, use **Eject** or **Safely remove**. The cartridge remains powered
while the active flash is erased, repacked and verified. Wait for steady green
before unplugging. The staging copy remains until the PC deletes it.

The firmware uses the file extension to choose flash layout. The physical SW2
mode is deliberately not changed by USB software; set it to match the installed
image only after USB has been disconnected and before console power is applied.

## Image rules

| Format | Minimum | Maximum | Header check | Flash packing |
| --- | ---: | ---: | --- | --- |
| MD/GEN/BIN | 512 B | 4,194,304 B | `SEGA` at `0x100` | two bytes/x16 word |
| 32X | 1 KiB | 4,194,304 B | `SEGA` at `0x100`; `MARS CHECK MODE` at `0x3C0` | two bytes/x16 word |
| SMS | 8 KiB | 2,097,152 B | `TMR SEGA` at `0x1FF0`, `0x3FF0`, or `0x7FF0` | one byte/x16 word |

Odd MD images receive an `0xFF` low-byte pad. `.32X` images must be a multiple
of four bytes and retain their original security/startup area. Smaller
power-of-two `.32X` images repeat through the complete 4 MiB cartridge range.
SMS images must be headerless binary dumps. Extension alone cannot make an
unsupported mapper, save device, or enhancement cartridge compatible.

## LEDs

| State | Green | Amber | Red |
| --- | --- | --- | --- |
| USB drive mounted | slow blink | off | off |
| PC writing staging flash | off | fast blink | off |
| Erasing/programming active ROM | off | steady | off |
| Install and verification successful | steady | off | off |
| No supported ROM, wrong size, or bad header | off | off | two-blink code |
| Flash/program/verify failure | off | off | steady |

The PROGRAM button requests the same install after pending USB writes are
flushed. Do not press it while the operating system is copying data.

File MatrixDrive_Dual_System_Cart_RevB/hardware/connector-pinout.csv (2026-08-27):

Contact | Console signal | Direction at cartridge | Rev B connection | Notes
A1 | GND | Power | GND | Ground
A2 | +5V | Power | CART_5V_IN | Join A31 before fuse F1
A3 | VA8 | Input | ADDR_XCVR_A7 | Cart address bit 7
A4 | VA11 | Input | ADDR_XCVR_A10 | Cart address bit 10
A5 | VA7 | Input | ADDR_XCVR_A6 | Cart address bit 6
A6 | VA12 | Input | ADDR_XCVR_A11 | Cart address bit 11
A7 | VA6 | Input | ADDR_XCVR_A5 | Cart address bit 5
A8 | VA13 | Input | ADDR_XCVR_A12 | Cart address bit 12
A9 | VA5 | Input | ADDR_XCVR_A4 | Cart address bit 4
A10 | VA14 | Input | ADDR_XCVR_A13 | Cart address bit 13
A11 | VA4 | Input | ADDR_XCVR_A3 | Cart address bit 3
A12 | VA15 | Input | ADDR_XCVR_A14 | Cart address bit 14
A13 | VA3 | Input | ADDR_XCVR_A2 | Cart address bit 2
A14 | VA16 | Input | ADDR_XCVR_A15 | Cart address bit 15
A15 | VA2 | Input | ADDR_XCVR_A1 | Cart address bit 1
A16 | VA17 | Input | ADDR_XCVR_A16 | Cart address bit 16
A17 | VA1 | Input | ADDR_XCVR_A0 | Cart address bit 0
A18 | GND | Power | GND | Ground
A19 | VD7 | Bidirectional | DATA_LOW_XCVR_A7 | ROM/SMS data bit 7 and mapper write data
A20 | VD0 | Bidirectional | DATA_LOW_XCVR_A0 | ROM/SMS data bit 0 and mapper write data
A21 | VD8 | Bidirectional | DATA_HIGH_XCVR_A0 | MD data bit 8; U7 disabled in SMS and MD Sonic 3 FRAM cycles
A22 | VD6 | Bidirectional | DATA_LOW_XCVR_A6 | ROM/SMS data bit 6
A23 | VD1 | Bidirectional | DATA_LOW_XCVR_A1 | ROM/SMS data bit 1
A24 | VD9 | Bidirectional | DATA_HIGH_XCVR_A1 | MD data bit 9; U7 disabled in SMS and MD Sonic 3 FRAM cycles
A25 | VD5 | Bidirectional | DATA_LOW_XCVR_A5 | ROM/SMS data bit 5
A26 | VD2 | Bidirectional | DATA_LOW_XCVR_A2 | ROM/SMS data bit 2
A27 | VD10 | Bidirectional | DATA_HIGH_XCVR_A2 | MD data bit 10; U7 disabled in SMS and MD Sonic 3 FRAM cycles
A28 | VD4 | Bidirectional | DATA_LOW_XCVR_A4 | ROM/SMS data bit 4
A29 | VD3 | Bidirectional | DATA_LOW_XCVR_A3 | ROM/SMS data bit 3
A30 | VD11 | Bidirectional | DATA_HIGH_XCVR_A3 | MD data bit 11; U7 disabled in SMS and MD Sonic 3 FRAM cycles
A31 | +5V | Power | CART_5V_IN | Join A2 before fuse F1
A32 | GND | Power | GND | Ground
B1 | SL1 | Not used on Rev B | NC | Optional FPGA spin injects filtered AC-coupled FM audio
B2 | /MRES | Input | CTRL2_XCVR_MRES | CPLD asynchronous mapper reset
B3 | SR2 | Not used on Rev B | NC | Optional FPGA spin injects filtered AC-coupled FM audio
B4 | VA9 | Input | ADDR_XCVR_A8 | Cart address bit 8
B5 | VA10 | Input | ADDR_XCVR_A9 | Cart address bit 9
B6 | VA18 | Input | ADDR_XCVR_A17 | MD address bit 17
B7 | VA19 | Input | ADDR_XCVR_A18 | MD address bit 18; active-low IORQ in SMS mode and FPGA FM qualifier
B8 | VA20 | Input | ADDR_XCVR_A19 | MD address bit 19
B9 | VA21 | Bidirectional mode | ADDR_XCVR_A20 and Q2 drain | MD address bit 20; open-drain low in SMS mode
B10 | VA22 | Mode | Q3 drain | Open-drain low in SMS mode; floating in MD mode
B11 | VA23 | Pause | Q4 drain | Open-drain PAUSE/NMI pulse in SMS mode only
B12 | /YS | Not used | NC | Video signal
B13 | /VSYNC | Not used | NC | Video signal
B14 | /HSYNC | Not used | NC | Video signal
B15 | EDCLK | Not used | NC | Video clock
B16 | /CAS0 | Input | CTRL_XCVR_CAS0 | ROM plus SMS and Sonic 3 FRAM output-enable timing
B17 | /CE_0 | Input | CTRL_XCVR_CE0 | MD ROM CE and SMS slots 0/1 select
B18 | /AS | Input | CTRL2_XCVR_AS | Translated for diagnostics and future profiles
B19 | VCLK | Input | TP_VCLK | Test point only
B20 | /DTACK | Open drain/unused | NC | Console supplies timing for standard ROM
B21 | /CAS2 | Input | CTRL_XCVR_CAS2 | SMS slot 2 ROM/FRAM select
B22 | VD15 | Bidirectional | DATA_HIGH_XCVR_A7 | MD data bit 15; U7 disabled in SMS and MD Sonic 3 FRAM cycles
B23 | VD14 | Bidirectional | DATA_HIGH_XCVR_A6 | MD data bit 14; U7 disabled in SMS and MD Sonic 3 FRAM cycles
B24 | VD13 | Bidirectional | DATA_HIGH_XCVR_A5 | MD data bit 13; U7 disabled in SMS and MD Sonic 3 FRAM cycles
B25 | VD12 | Bidirectional | DATA_HIGH_XCVR_A4 | MD data bit 12; U7 disabled in SMS and MD Sonic 3 FRAM cycles
B26 | /ASEL | Input | NC | Not required
B27 | /VRES | Input | TP_VRES | Test point only
B28 | /LWR | Input | CTRL2_XCVR_LWR and U16 input | SMS writes and MD odd-byte Sonic 3 FRAM write strobe
B29 | /UWR | Input | CTRL2_XCVR_UWR | Translated for diagnostics; Sonic 3 FRAM is odd-byte only and uses /LWR
B30 | /M3 | Mode | Q1 drain | Open-drain low in SMS mode; floating in MD mode
B31 | /TIME | Input | CTRL2_XCVR_TIME | Translated for diagnostics; Sonic & Knuckles owns its $A130F0 lock-on control
B32 | /CART | Output | 0R to GND | Selects bootable cartridge mapping

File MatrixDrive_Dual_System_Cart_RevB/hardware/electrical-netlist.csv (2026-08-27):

Net | From | To | Direction or rule
CART_5V_IN | J1.A2 and J1.A31 | F1.1 | Join both edge power contacts
CART_5V | F1.2 | D1.A; U3-U8.VCCA/VCC as applicable; U14-U16.VCCA/VCC; U19.VCCB | Console-only 5V domain
USB_VBUS | J2.VBUS | D2.A; R5.1; R7.1; R29.1 | USB source plus two independent presence dividers
SYS_5V | D1.K and D2.K | U11.IN; C23.1 | Diode-ORed supply
3V3 | U11.OUT | U1/U2/U9/U10/U13/U17-U20 supplies; U3-U7/U14 VCCB; C decoupling | Digital 3.3V rail
GND | J1.A1/A18/A32; J2.GND; all IC grounds | Ground plane | Single continuous plane
USB_DP | J2.DP | R3.1 | Route 90ohm differential with USB_DM
USB_DP_MCU | R3.2 | U1.USB_DP | Short matched pair
USB_DM | J2.DM | R4.1 | Route 90ohm differential with USB_DP
USB_DM_MCU | R4.2 | U1.USB_DM | Short matched pair
USB_ESD | USB_DP; USB_DM | U12.IO1/IO2 | U12 beside J2 with short ground return
CC1 | J2.CC1 | R1.1 | R1.2 to GND
CC2 | J2.CC2 | R2.1 | R2.2 to GND
BUS_DISABLE | U8.Y | U3-U6./OE; U14./OE; U15.1A | Low enables console translation; USB with console present drives high
DATA_HIGH_BASE_DISABLE | U15.1Y | U15.2A | Logical BUS_DISABLE OR SMS_MODE_5V
MD_HIGH_DISABLE_3V3 | U13.md_high_disable | U19.A | High only during the Sonic 3 odd-byte FRAM window or USB coexistence
MD_HIGH_DISABLE_5V | U19.B | U15.2B | U19 translates the CPLD request into the CART_5V logic domain
DATA_HIGH_DISABLE | U15.2Y | U7./OE | High disables upper data byte for SMS USB coexistence or MD odd-byte FRAM
CART_A0-7 | U3.B0-B7 | U13.cart_a0-7; U17.A0-7; U18.A0-7; U20.A0-7 | U3 A-side from J1 VA1-VA8
CART_A8-12 | U4.B0-B4 | U13.cart_a8-12; U17.A8-12; U18.A8-12; U20.A8-12 | Translated address and FRAM 8 KiB window offset
CART_A13 | U4.B5 | U13.cart_a13 | Translated address; FRAM A13 is mapper-controlled
CART_A14-15 | U4.B6-B7 | U13.cart_a14-15 | Translated Z80/68000 address
CART_A16-20 | U5.B0-B4 | U13.cart_a16-20 | Translated MD address; A18 is VA19 active-low IORQ in SMS mode and taps optional FM FPGA; A20 is pulled low in SMS mode
CE0_3V3 | U5.B5 | U13.ce0_n | U5.A5 from J1.B17
CAS0_3V3 | U5.B6 | U13.cas0_n | U5.A6 from J1.B16
CAS2_3V3 | U5.B7 | U13.cas2_n | U5.A7 from J1.B21
LWR_3V3 | U14.B0 | U13.lwr_n | U14.A0 from J1.B28
MRES_3V3 | U14.B1 | U13.reset_n; R41.1 | U14.A1 from J1.B2; R41.2 to GND
UWR_3V3 | U14.B2 | TP_UWR_3V3 | U14.A2 from J1.B29
AS_3V3 | U14.B3 | TP_AS_3V3 | U14.A3 from J1.B18
TIME_3V3 | U14.B4 | TP_TIME_3V3 | U14.A4 from J1.B31
CTRL2_UNUSED | U14.A5-A7 | GND | Do not leave enabled translator inputs floating; B5-B7 no-connect
LOW_DATA_DIR | U16.Y | U6.DIR | U16.A from J1.B28 LWR_N; high only during low-byte writes
MEM_D0-7 | U6.B0-B7 | U2.DQ0-DQ7; U17.DQ0-DQ7; U18.DQ0-DQ7; U20.DQ0-DQ7; U13.data_in0-7; U1.GPIO21-28 | U6 A-side to J1 VD0-VD7; bidirectional by LOW_DATA_DIR
MEM_D8-15 | U7.B0-B7 | U2.DQ8-DQ15; U1.GPIO29-36 | U7 DIR low; A-side to J1 VD8-VD15; disabled in SMS mode
ROM_A0-20 | U13.rom_a0-20 | U2.A0-A20; U1.GPIO0-20 | CPLD drives console mapping; tri-states for USB programming
ROM_CE_N | U13.rom_ce_n | U2.CE_N; U1.GPIO37; R31.1 | R31.2 to 3V3; CPLD releases in USB mode
ROM_OE_N | U13.rom_oe_n | U2.OE_N; U1.GPIO38; R32.1 | R32.2 to 3V3; CPLD releases in USB mode
ROM_WE_N | U1.GPIO39 | U2.WE_N; R12.1 | R12.2 to 3V3; MCU input unless programming
FRAM_A13 | U13.fram_a13 | U17.A13; U18.A13; R42.1 | R42.2 to GND; Sega follows CPU A13; Codemasters bank bit 0
FRAM_A14 | U13.fram_a14 | U17.A14; U18.A14; R33.1 | R33.2 to GND; Sega bank bit; Codemasters bank bit 1
FRAM_CE_N | U13.fram_ce_n | U17.CE_N; R34.1 | R34.2 to 3V3; logical FRAM A15=0
FRAM_HI_CE_N | U13.fram_hi_ce_n | U18.CE_N; R43.1 | R43.2 to 3V3; logical SMS FRAM A15=1
MD_FRAM_CE_N | U13.md_fram_ce_n | U20.CE_N; R45.1 | R45.2 to 3V3; dedicated Sonic 3 8 KiB odd-byte save window
MD_FRAM_STATIC_ADDR | U20.A13/A14 | GND | Only U20 A0-A12 are used for the 8 KiB save window
FRAM_OE_N | U13.fram_oe_n | U17.OE_N; U18.OE_N; U20.OE_N; R35.1 | R35.2 to 3V3
FRAM_WE_N | U13.fram_we_n | U17.WE_N; U18.WE_N; U20.WE_N; R36.1 | R36.2 to 3V3
USB_MODE_3V3 | R29.2; R30.1 | U13.usb_mode | R30.2 to GND; independent VBUS/2 sense for CPLD output release
SMS_MODE_3V3 | SW2 pole A common | U13.sms_mode; Q1-Q3 gates; SW3.1 | SW2 selects 3V3 in SMS and GND in MD; R37-R39 pull gates down
SMS_MODE_5V | SW2 pole B common | U15.1B | SW2 selects CART_5V in SMS and GND in MD
SMS_MAPPER_CM_3V3 | SW4 common | U13.codemasters_mapper; R44.1 | R44.2 to GND; SMS selects Sega/Codemasters while MD selects linear/Sonic 3 save; power-off only
PAUSE_GATE | SW3.2 | Q4.G; R40.1 | R40.2 to GND; only high when SMS_MODE_3V3 exists and SW3 pressed
M3_OPEN_DRAIN | Q1.D | J1.B30 | Q1.S to GND; never pull up
VA21_OPEN_DRAIN | Q2.D | J1.B9 | Q2.S to GND; also translated as address in MD
VA22_OPEN_DRAIN | Q3.D | J1.B10 | Q3.S to GND; never pull up
PAUSE_OPEN_DRAIN | Q4.D | J1.B11 | Q4.S to GND; SMS NMI pause
CART_N | J1.B32 | R13.1 | R13.2 to GND
DIR_ADDR_CTRL | U3-U5.DIR; U14.DIR | CART_5V | Translate console A-side to 3V3 B-side
DIR_DATA_HIGH | U7.DIR | GND | Translate 3V3 memory B-side to console A-side
DIR_MD_HIGH_DISABLE | U19.DIR | 3V3 | Transmit U19 A-side 3V3 request to B-side CART_5V logic
ROM_STATIC_STRAPS | U2.RESET_N/WP_N/BYTE_N or mode pins | R25-R27 to 3V3 as required | Confirm exact names/polarities from ordered package datasheet
BOOT_QSPI | U1.QSPI pins | U9.CS/CLK/IO0-3 | Dedicated XIP bus per current RP2350 reference
STAGE_MISO | U1.GPIO40 | U10.DO | SPI1 RX staging flash
STAGE_CS | U1.GPIO41 | U10.CS_N | GPIO-controlled chip select
STAGE_SCK | U1.GPIO42 | U10.CLK | SPI1 SCK staging flash
STAGE_MOSI | U1.GPIO43 | U10.DI | SPI1 TX staging flash
USB_SENSE_PROGRAM | U1.GPIO44 | R7.2; R8.1; SW1.1 | R8.2 and SW1.2 to GND; VBUS/2 normally and low on button
LED_GREEN | U1.GPIO45 | R9.1 | R9.2 to D3 anode; LED cathode GND
LED_AMBER | U1.GPIO46 | R10.1 | R10.2 to D4 anode; LED cathode GND
LED_RED | U1.GPIO47 | R11.1 | R11.2 to D5 anode; LED cathode GND
CPLD_JTAG | U13.TCK/TMS/TDI/TDO | J4 | J4 also carries 3V3 and GND; do not expose 5V

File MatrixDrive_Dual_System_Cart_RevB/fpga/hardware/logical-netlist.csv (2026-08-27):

Net | From | To | Direction or rule
FM_CLK_14M318 | X1.OUT | U21.clk_14m318 | 3.3V clock with source termination only if required by layout review
FM_RESET_N | MRES_3V3 | U21.reset_n | Translated console hard reset
FM_SMS_MODE | SMS_MODE_3V3 | U21.sms_mode | High only in hardware SMS position
FM_USB_MODE | USB_MODE_3V3 | U21.usb_mode | High releases every cartridge-bus FPGA output
FM_ADDR0-7 | CART_A0-7 | U21.cart_a0-7 | Translated SMS low address byte
FM_IORQ_N | CART_A18 | U21.cart_a18_iorq_n | VA19 becomes active-low IORQ in SMS mode; mandatory decode qualifier
FM_WR_N | LWR_3V3 | U21.lwr_n | Translated SMS write strobe
FM_RD_N | CAS0_3V3 | U21.cas0_n | Translated SMS read/output-enable strobe
FM_DATA0-7 | MEM_D0-7 | U21.mem_d0-7 | Bidirectional 3.3V bus; FPGA drives only exact F2 I/O reads
FM_PDM | U21.fm_pdm | R46.1 | One-bit 14.31818MHz audio stream
FM_LP1 | R46.2 | C37.1; R47.1 | C37.2 to GND
FM_LP2 | R47.2 | C38.1; C39.1 | C38.2 to GND
FM_AUDIO_AC | C39.2 | R48.1; R49.1; R50.1 | R50.2 to GND
FM_AUDIO_LEFT | R48.2 | J1.B1 SL1 | AC-coupled cartridge audio injection
FM_AUDIO_RIGHT | R49.2 | J1.B3 SR2 | AC-coupled cartridge audio injection
FM_1V1 | U23.OUT | U21.VCC | Core rail; decouple every package power group
FM_2V5 | U24.OUT | U21.VCCAUX | Auxiliary rail; follow current ECP5 hardware checklist
3V3 | Existing board 3V3 | U21 VCCIO/config banks; U22; X1; U23.IN; U24.IN | Recalculate shared regulator and cartridge current budget
FPGA_CONFIG | U22 SPI; J5 JTAG | U21 sysCONFIG | Select and document one boot mode before schematic release

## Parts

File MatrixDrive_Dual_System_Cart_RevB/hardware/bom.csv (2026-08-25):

Reference | Quantity | Value or part | Description | Preferred footprint | Populate Rev B | Notes
U1 | 1 | RP2350B | USB and flash controller | QFN-80-1EP 10x10mm | Yes | Use RP2350B for GPIO0-47
U2 | 1 | S29GL032N90TFI040 | 32-Mbit 3V x16 parallel NOR | TSOP-I-48 18.4x12mm | Yes | 90ns or faster; verify purchased package pinout
U3-U5 | 3 | SN74LVC8T245PWR | Address and primary-control 5V-to-3V3 translators | TSSOP-24 | Yes | DIR A to B
U6 | 1 | SN74LVC8T245PWR | Low data byte bidirectional translator | TSSOP-24 | Yes | DIR from U16 so SMS writes reach CPLD and FRAM
U7 | 1 | SN74LVC8T245PWR | High data byte 3V3-to-5V translator | TSSOP-24 | Yes | Disabled by U15 in SMS mode
U8 | 1 | SN74LVC1G17DBVR | USB-present bus-disable buffer | SOT-23-5 | Yes | Powered from CART_5V; require Ioff
U9 | 1 | W25Q16JVSSIQ | 2-MiB RP2350 QSPI boot flash | SOIC-8 5.3mm | Yes | Dedicated XIP device
U10 | 1 | W25Q128JVSIQ | 16-MiB USB staging SPI NOR | SOIC-8 5.3mm | Yes | Dedicated FAT16 volume
U11 | 1 | TLV75533PDBVR | 500mA 3.3V LDO | SOT-23-5 | Yes | Input from SYS_5V
U12 | 1 | TPD2EUSB30DRTR | USB D+/D- ESD protector | SOT-9/DRT | Yes | Place beside J2
U13 | 1 | ATF1508ASV-15AU100 | Instant-on SMS mapper and MD lock-on save decoder CPLD | TQFP-100 14x14mm | Yes | 3.3V; fit/timing and pins are release gates
U14 | 1 | SN74LVC8T245PWR | Secondary-control 5V-to-3V3 translator | TSSOP-24 | Yes | Translates LWR MRES UWR AS and TIME
U15 | 1 | SN74LVC2G32DCUR | Cascaded upper-data output-disable OR gates | VSSOP-8 | Yes | Powered CART_5V; also disables U7 during MD odd-byte FRAM cycles
U16 | 1 | SN74LVC1G04DBVR | Low-data direction inverter | SOT-23-5 | Yes | Powered CART_5V; U6 DIR = NOT LWR_N
U17-U18 | 2 | FM18W08-SG | 32Kx8 nonvolatile SMS save FRAM each | SOIC-28 wide | Yes | 64 KiB total; low/high halves use separate CPLD chip enables
U19 | 1 | SN74LVC1T45DBVR | 3V3-to-5V MD high-data-disable translator | SOT-23-6 | Yes | VCCA=3V3 VCCB=CART_5V DIR high; Ioff and VCC isolation required
U20 | 1 | FM18W08-SG | 32Kx8 dedicated Sonic 3 lock-on save FRAM | SOIC-28 wide | Yes | Only 8 KiB is decoded at odd byte addresses $200001-$203FFF
J1 | 1 | 2x32 2.54mm card edge | Mega Drive cartridge edge | PCB gold fingers | Yes | Hard gold and bevel required
J2 | 1 | USB4105-GF-A | USB-C USB2 receptacle | USB-C 16-pin with shell stakes | Yes | Device/UFP only
J3 | 1 | 2x5 1.27mm header | SWD debug and UART header | PinHeader 2x05 P1.27mm | Optional | DNP after production programming
J4 | 1 | 2x5 1.27mm header | CPLD JTAG programming header | PinHeader 2x05 P1.27mm | Yes | Keep accessible during prototype work
Y1 | 1 | ABM8-272-T3 | 12MHz crystal | 3.2x2.5mm 4-pad | Yes | Match RP2350 hardware-guide network
L1 | 1 | AOTA-B201610S3R3-101-T | 3.3uH polarised RP2350 core-regulator inductor | 2.0x1.6mm vendor footprint | Yes | Copy orientation and placement from current official design
F1 | 1 | MF-MSMF020-2 | 200mA resettable fuse | 1812 | Yes | Revalidate against measured dual-system current
D1-D2 | 2 | PMEG2010AEB | 1A low-drop Schottky | SOD-523 | Yes | Source isolation into SYS_5V
D3-D5 | 3 | LTST-C190KGKT/LTST-C190YKT/LTST-C190KRKT | Green amber red status LEDs | 0603 | Yes | Use separate current resistors
Q1-Q4 | 4 | 2N7002 | Open-drain M3 VA21 VA22 and PAUSE pulls | SOT-23 | Yes | Gates never connect directly to 5V bus
R1-R2 | 2 | 5.1k 1% | USB-C CC1 and CC2 Rd | 0603 | Yes | One resistor per CC pin
R3-R4 | 2 | 27R 1% | USB D+/D- series resistors | 0603 | Yes | Place near U1
R5 | 1 | 10k | USB_VBUS to U8 input series resistor | 0603 | Yes
R6 | 1 | 100k | U8 input pulldown | 0603 | Yes
R7-R8 | 2 | 100k | USB detect and PROGRAM ADC divider | 0603 | Yes | GPIO44 sees VBUS/2; SW1 parallels R8
R9-R11 | 3 | 1k | LED current resistors | 0603 | Yes
R12 | 1 | 10k | ROM_WE_N pullup | 0603 | Yes | Prevents accidental active-NOR writes
R13 | 1 | 0R | /CART strap to GND | 0603 | Yes
R14 | 1 | 100k | BUS_DISABLE pulldown | 0603 | Yes | Keeps pass-through enabled during CART_5V ramp
R15-R18 | 4 | 10k | Optional translator OE pulldowns | 0603 | DNP | Common BUS_DISABLE is authoritative
R19-R23 | 5 | 10k | Translator DIR straps | 0603 | Yes | U3-U5/U14 high and U7 low; U6 is dynamic
R24 | 1 | 33R 1% | RP2350 VREG_AVDD filter resistor | 0603 | Yes | Confirm against current official reference
R25-R27 | 3 | 10k | Parallel-flash RESET/WP/mode straps | 0603 | Yes | Confirm names and polarities for exact package
R28 | 1 | 1k 1% | RP2350 crystal series resistor | 0402/0603 | Yes | Copy official position and connection
R29-R30 | 2 | 100k | Independent USB_MODE_3V3 divider | 0603 | Yes | USB_VBUS/2 to U13; never share PROGRAM button node
R31-R32 | 2 | 10k | ROM CE/OE inactive pullups | 0603 | Yes | Holds NOR inactive whenever U13 releases outputs
R33 | 1 | 10k | FRAM A14 pulldown | 0603 | Yes | Defaults address low whenever U13 releases output
R34-R36 | 3 | 10k | Low FRAM CE plus shared OE/WE inactive pullups | 0603 | Yes | Holds U17 and shared controls inactive
R37-R40 | 4 | 100k | Open-drain FET gate pulldowns | 0603 | Yes | MD and PAUSE default inactive
R41 | 1 | 100k | MRES_3V3 reset pulldown | 0603 | Yes | CPLD mapper defaults held until console reset arrives
R42 | 1 | 10k | FRAM A13 pulldown | 0603 | Yes | Defaults address low whenever U13 releases output
R43 | 1 | 10k | High FRAM CE inactive pullup | 0603 | Yes | Holds U18 inactive whenever U13 releases output
R44 | 1 | 100k | SW4 profile-select pulldown | 0603 | Yes | Defaults to Sega in SMS mode and linear/no-save in MD mode
R45 | 1 | 10k | Dedicated MD FRAM CE inactive pullup | 0603 | Yes | Holds U20 inactive whenever U13 releases output
C1-C18 | 18 | 100nF X7R | Local digital decoupling | 0603 | Yes | One at every IC rail pair plus MCU groups
C19-C22 | 4 | 1uF X7R | Bulk/local decoupling | 0603 | Yes | Flash CPLD and translator banks
C23-C24 | 2 | 10uF X7R | Regulator input/output bulk | 0805 | Yes | Check LDO stability guidance
C25-C26 | 2 | 15pF C0G 5% | Crystal load capacitors | 0402/0603 | Yes | Recalculate for layout and specified crystal
C27 | 1 | 4.7uF X7R | RP2350 1V1 core output capacitor | 0603 | Yes | Copy current official design
C28-C33 | 6 | TBD per official reference | RP2350 regulator ADC and IO support capacitors | 0402/0603 | Yes | Do not release until copied from current minimal design
C34 | 1 | 100nF X7R | U18 local decoupling | 0603 | Yes | Place at U18 VDD
C35-C36 | 2 | 100nF X7R | U19 and U20 local decoupling | 0603 | Yes | Place at each new device supply
SW1 | 1 | PTS636 | Manual PROGRAM button | SMD 6x3.5mm | Yes | Pulls GPIO44 ADC ladder low only while USB mounted
SW2 | 1 | DPDT break-before-make slide | MD/SMS hardware mode switch | SMD right-angle slide | Yes | One pole 3V3 mode/FET gates; one pole 5V U7 disable
SW3 | 1 | PTS636 | Master System PAUSE button | SMD 6x3.5mm | Yes | Drives Q4 gate only from SMS_MODE_3V3
SW4 | 1 | SPDT break-before-make slide | SMS mapper / MD lock-on-save profile selector | SMD right-angle slide | Yes | Low=SEGA or LINEAR; high=CODEMASTERS or S3 SAVE; move only unpowered
TP1-TP22 | 22 | Test points | Power mode bus mapper and lock-on diagnostics | 1.0mm SMD pad | Yes | Include USB_MODE MD_FRAM_CE and MD_HIGH_DISABLE

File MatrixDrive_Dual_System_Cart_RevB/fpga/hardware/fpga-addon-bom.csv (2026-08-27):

Reference | Quantity | Value or part | Description | Preferred footprint | Populate FPGA spin | Notes
U21 | 1 | LFE5U-12F-6BG256C | 12K-LUT ECP5 FPGA | CABGA-256 | Yes | Final package pin assignment and escape are release gates
U22 | 1 | W25Q16JVSSIQ | 16-Mbit FPGA configuration SPI NOR | SOIC-8 5.3mm | Yes | Wire to ECP5 sysCONFIG per current Lattice guidance
U23 | 1 | TLV75511PDBVR | 1.1V FPGA core LDO | SOT-23-5 | Yes | Size from post-route power estimate and measured load
U24 | 1 | TLV75525PDBVR | 2.5V FPGA auxiliary LDO | SOT-23-5 | Yes | Size from post-route power estimate and measured load
X1 | 1 | 14.318180MHz 3.3V CMOS oscillator | FPGA emulation clock | 2.5x2.0mm 4-pad | Yes | Low-jitter part chosen for the final supply and temperature range
J5 | 1 | 2x5 1.27mm header | FPGA JTAG and configuration debug | PinHeader 2x05 P1.27mm | Prototype | DNP after production programming only after recovery path is proven
R46-R47 | 2 | 2.2k 1% | Two-pole PDM reconstruction filter | 0603 | Yes | Each forms approximately 15.4kHz pole with 4.7nF
R48-R49 | 2 | 10k 1% | Left and right cartridge audio injection | 0603 | Yes | Tune only after measuring SL1 and SR2 on target consoles
R50 | 1 | 100k | AC-side audio reference to ground | 0603 | Yes | Keeps output defined while console is absent
R51 | 1 | 33R 1% | FPGA oscillator source termination | 0603 | Review | Place based on final clock routing and IBIS review
C37-C38 | 2 | 4.7nF C0G 5% | Two-pole PDM reconstruction filter | 0603 | Yes | Place after each 2.2k stage
C39 | 1 | 1uF X7R 16V | Audio DC blocking capacitor | 0603/0805 | Yes | Use non-polar dielectric and check voltage coefficient
C40-C55 | 16 | 100nF X7R | FPGA rail and configuration decoupling | 0402/0603 | Yes | Final count and placement follow package power-pin map
C56-C61 | 6 | 4.7uF X7R | FPGA rail local bulk decoupling | 0603/0805 | Yes | Final values follow regulator and FPGA power guidance
R52-R59 | 8 | TBD | Configuration and JTAG straps/pulls | 0603 | Yes | Do not assign values until configuration mode is selected

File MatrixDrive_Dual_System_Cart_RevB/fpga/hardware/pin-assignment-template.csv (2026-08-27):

Top-level port | Width | Logical board net | Package pin | I/O standard | Required constraint/status
clk_14m318 | 1 | FM_CLK_14M318 |  | LVCMOS33 | Dedicated/global-capable input; create 69.841ns clock
reset_n | 1 | FM_RESET_N |  | LVCMOS33 | Input only with defined pull state
sms_mode | 1 | FM_SMS_MODE |  | LVCMOS33 | Input only with defined pull state
usb_mode | 1 | FM_USB_MODE |  | LVCMOS33 | Input only with defined pull state
cart_a | 8 | FM_ADDR0-7 |  | LVCMOS33 | Input-only bank; preserve bit order
cart_a18_iorq_n | 1 | FM_IORQ_N |  | LVCMOS33 | Input only; asynchronous control synchronized in RTL
lwr_n | 1 | FM_WR_N |  | LVCMOS33 | Input only; asynchronous control synchronized in RTL
cas0_n | 1 | FM_RD_N |  | LVCMOS33 | Input only; timing included in F2 read path
mem_d | 8 | FM_DATA0-7 |  | LVCMOS33 | Bidirectional bank; prove high-Z during configuration MD and USB modes
fm_pdm | 1 | FM_PDM |  | LVCMOS33 | Output with low drive/slew sufficient for 14.31818MHz
fm_active | 1 | TESTPOINT_ONLY |  | LVCMOS33 | Optional test point or leave unbonded in wrapper variant
fm_core_ready | 1 | TESTPOINT_ONLY |  | LVCMOS33 | Optional test point or leave unbonded in wrapper variant

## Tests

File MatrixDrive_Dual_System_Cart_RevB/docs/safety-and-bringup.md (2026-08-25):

# Safety and first bring-up

This is prototype hardware for ageing original equipment. Complete every bench check before inserting it into a Mega Drive/Genesis, 32X, or Sonic & Knuckles cartridge.

## Assembly and mechanical inspection

1. Confirm PCB thickness, hard-gold fingers, bevel, contact pitch, A/B orientation, and insertion depth against a known-good Mega Drive cartridge.
2. Measure the Sonic & Knuckles upper-slot opening, door/latch travel, shell wall, component height, and extraction clearance. Do not assume direct-console fit proves upper-slot fit.
3. Measure the real 32X cartridge-slot opening, door travel, shell wall, component height, insertion depth, and extraction clearance.
4. Check all QFN, TSOP, SOIC, translator, and USB-C pins under magnification.
5. Verify `/CART` is grounded. In MD mode `/M3`, VA21, and VA22 must float; in SMS mode only their open-drain FETs may pull low.
6. Confirm SW4 low means SEGA/LINEAR and high means CODEMASTERS/S3 SAVE.
7. Measure resistance from every supply rail to ground before applying power.

## USB-only test

Use a current-limited 5 V supply set initially to 100 mA.

1. Apply 5 V at `USB_VBUS` with `CART_5V` disconnected.
2. Confirm `SYS_5V` and `3V3` before fitting the RP2350B or memories.
3. Confirm no measurable voltage appears at cartridge contacts A2/A31.
4. Confirm the PC enumerates `MATRIXDRV`.
5. Confirm every cartridge-facing translator pin is high impedance.
6. Confirm U17, U18, and U20 chip enables remain inactive.

## Console-supply simulation

Do not use a console for this stage. Apply current-limited 5 V at `CART_5V` through a cartridge breakout.

1. Leave USB disconnected and confirm `BUS_DISABLE` is low.
2. Confirm each dual-supply translator has the intended 5 V and 3.3 V rails.
3. Confirm RP2350 parallel-bus GPIOs remain inputs.
4. In MD/LINEAR, compare NOR address and data patterns with a logic analyser.
5. In MD/S3 SAVE, sweep word addresses `$0FFFFF-$102000` and verify U20 is selected only at `$100000-$101FFF`.
6. During U20 reads/writes, verify ROM CE/OE are inactive, U17/U18 remain disabled, U7 OE is high, U6 has the correct direction, and `/CAS0`/`/LWR` meet U20 timing.
7. In SMS/SEGA, verify reset banks 0/1/2, `$FFFC-$FFFF`, the fixed first 1 KiB, and both 16 KiB FRAM banks.
8. In SMS/CODEMASTERS, verify exact mapper writes, ROM at `$8000-$9FFF`, and all eight 8 KiB FRAM banks.
9. Confirm worst-case translator+CPLD+NOR/FRAM delay meets the console bus windows.

## Dual-source isolation test

1. Apply current-limited 5 V independently to both sources.
2. Confirm no reverse current enters either source.
3. Confirm `BUS_DISABLE` rises close to `CART_5V`.
4. Confirm console-facing translators become high impedance before RP2350 GPIOs drive the NOR bus.
5. Confirm `USB_MODE_3V3` releases NOR and all FRAM controls and `md_high_disable` requests upper-byte isolation.

## First direct-console test

1. Use a protected cartridge breakout where possible.
2. Program a small known-good MD diagnostic.
3. Disconnect USB, choose MD/LINEAR, insert MatrixDrive directly, and power on through a current monitor.
4. Stop immediately for abnormal current, heat, or out-of-rail bus levels.
5. Repeat with an SMS diagnostic and verify PAUSE/NMI.

## First 32X test

Only begin after direct-console MD tests pass.

1. Use a legally obtained, known-good ROM-only `.32X` diagnostic or game no larger than 4 MiB.
2. With all power removed, choose MD/LINEAR and insert MatrixDrive into the real 32X cartridge slot.
3. Install and connect the 32X normally, including its power and video-link cables.
4. Power the stack through a current monitor and verify the 32X startup/security sequence completes.
5. Stop immediately for abnormal current, heat, boot loops, or out-of-rail bus levels.
6. Capture `/CE_0`, `/CAS0`, address, and data timing at low, banked, and top-of-ROM addresses.
7. Power off and remove the complete stack before reconnecting USB.

See `32x-mode.md` for the exact image checks and unsupported save hardware.

## First Sonic & Knuckles test

Only begin after direct-console tests pass.

1. Clean and inspect both sets of contacts on an original Sonic & Knuckles cartridge.
2. With all power removed, load a legal Sonic 2 image, choose MD/LINEAR, insert MatrixDrive into the upper slot, then insert the lock-on cartridge into the console.
3. Power through a current monitor and verify Sonic 2 & Knuckles boot/read timing.
4. Power off and remove the complete stack before changing the image or switches.
5. Load a legal Sonic 3 image, choose MD/S3 SAVE, and repeat.
6. Verify U20 save writes and persistence; confirm U17/U18 contents do not change.
7. Capture `/CE_0`, `/CAS0`, `/LWR`, VA21, U7 OE, ROM CE, and U20 CE for the archive.

Never hot-plug either cartridge. Never connect USB to a stacked cartridge. Do not attach an oscilloscope earth clip until the console/test-equipment grounding arrangement is verified.

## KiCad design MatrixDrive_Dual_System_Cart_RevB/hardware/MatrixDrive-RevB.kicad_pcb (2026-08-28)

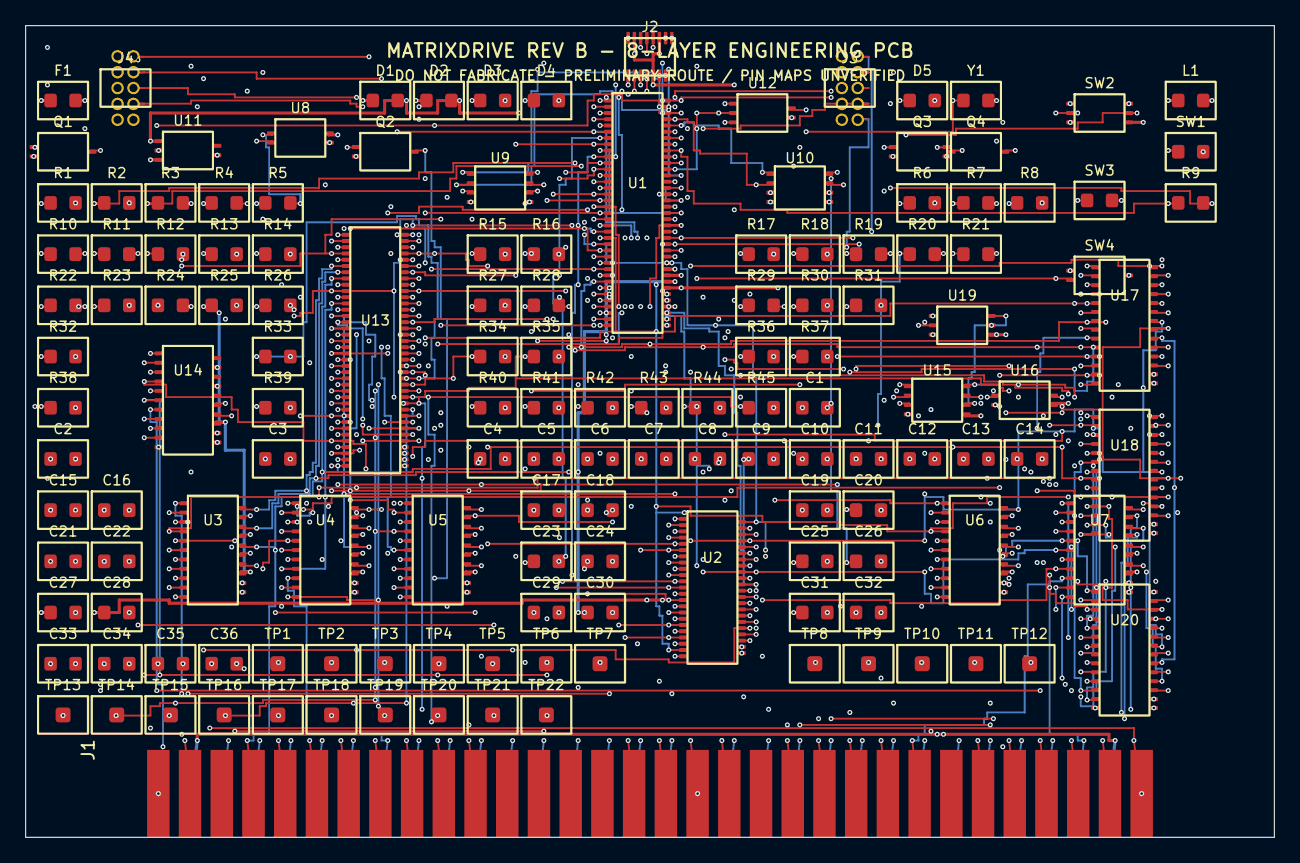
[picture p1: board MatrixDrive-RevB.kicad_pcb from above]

Board: 8 copper layers, 100.0 x 65.0 mm, 143 parts (0 on the bottom side), 190 nets.

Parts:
C1, C2, C3, C4, C5, C6, C7, C8, C9, C10, C11, C12, C13, C14, C15, C16, C17, C18, C34, C35, C36: 100nF; 0603
C19, C20, C21, C22: 1uF; 0603
C23, C24: 10uF; 0805
C25, C26: 15pF; 0402
C27: 4.7uF; 0603
C28, C29, C30, C31, C32, C33: TBD_REF; 0402
D1, D2: PMEG2010AEB; SOD_523
D3: GREEN_LED; 0603_LED
D4: AMBER_LED; 0603_LED
D5: RED_LED; 0603_LED
F1: MF-MSMF020-2; 1812
J1: MEGA_DRIVE_EDGE; MD_2x32_EDGE
J2: USB4105-GF-A; USB_C_16P
J3: SWD_UART_2x5 DNP; HDR_2x5_1_27
J4: CPLD_JTAG_2x5; HDR_2x5_1_27
L1: 3.3uH; 2016
Q1, Q2, Q3, Q4: 2N7002; SOT_23
R1, R2: 5.1k; 0603
R3, R4: 27R; 0603
R5, R12, R19, R20, R21, R22, R23, R25, R26, R27, R31, R32, R33, R34, R35, R36, R42, R43, R45: 10k; 0603
R6, R7, R8, R14, R29, R30, R37, R38, R39, R40, R41, R44: 100k; 0603
R9, R10, R11, R28: 1k; 0603
R13: 0R; 0603
R15, R16, R17, R18: 10k DNP; 0603
R24: 33R; 0603
SW1: PROGRAM; SW_2P
SW2: MD_SMS_DPDT; SW_DPDT_6P
SW3: SMS_PAUSE; SW_2P
SW4: PROFILE_SPDT; SW_SPDT_3P
TP1: CART_5V; TP_SMD_1MM
TP2: USB_VBUS; TP_SMD_1MM
TP3: SYS_5V; TP_SMD_1MM
TP4: 3V3; TP_SMD_1MM
TP5: GND; TP_SMD_1MM
TP6: BUS_DISABLE; TP_SMD_1MM
TP7: SMS_MODE_3V3; TP_SMD_1MM
TP8: SMS_MODE_5V; TP_SMD_1MM
TP9: USB_MODE_3V3; TP_SMD_1MM
TP10: ROM_CE_N; TP_SMD_1MM
TP11: ROM_OE_N; TP_SMD_1MM
TP12: ROM_WE_N; TP_SMD_1MM
TP13: FRAM_CE_N; TP_SMD_1MM
TP14: FRAM_HI_CE_N; TP_SMD_1MM
TP15: FRAM_OE_N; TP_SMD_1MM
TP16: FRAM_WE_N; TP_SMD_1MM
TP17: MD_FRAM_CE_N; TP_SMD_1MM
TP18: MD_HIGH_DISABLE_3V3; TP_SMD_1MM
TP19: LWR_3V3; TP_SMD_1MM
TP20: UWR_3V3; TP_SMD_1MM
TP21: AS_3V3; TP_SMD_1MM
TP22: TIME_3V3; TP_SMD_1MM
U1: RP2350B; UNVERIFIED_LOGICAL_PACKAGE
U2: S29GL032N90TFI040; TSOP_I_48_UNVERIFIED_PINMAP
U3, U4, U5, U6, U7, U14: SN74LVC8T245PWR; TSSOP_24_LOGICAL
U8: SN74LVC1G17DBVR; SOT_23_5
U9: W25Q16JVSSIQ; SOIC_8
U10: W25Q128JVSIQ; SOIC_8
U11: TLV75533PDBVR; SOT_23_5
U12: TPD2EUSB30DRTR; DRT_9_LOGICAL
U13: ATF1508ASV-15AU100; TQFP_100_UNASSIGNED
U15: SN74LVC2G32DCUR; VSSOP_8
U16: SN74LVC1G04DBVR; SOT_23_5
U17, U18, U20: FM18W08-SG; SOIC_28_LOGICAL
U19: SN74LVC1T45DBVR; SOT_23_6
Y1: 12MHz_CRYSTAL; 3225_4P

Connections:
1V1: C27.1, C28.1, L1.2, U1.DVDD, U1.VREG_FB
3V3: C1.1, C2.1, C3.1, C4.1, C5.1, C6.1, C7.1, C8.1, C9.1, C10.1, C11.1, C12.1, C13.1, C14.1, C15.1, C16.1, C17.1, C18.1, C19.1, C21.1, C22.1, C24.1, C29.1, C32.1, C33.1, C34.1, C35.1, C36.1, J3.1, J4.1, R12.2, R24.1, R25.2, R26.2, R27.2, R31.2, R32.2, R34.2, R35.2, R36.2, R43.2, R45.2, SW2.3, SW4.3, TP4.1, U1.IOVDD_1, U1.IOVDD_2, U1.VREG_IN, U2.VCC, U3.VCCB, U4.VCCB, U5.VCCB, U6.VCCB, U7.VCCB, U9.8, U10.3, U10.7, U10.8, U11.5, U13.VCC_1, U13.VCC_2, U14.VCCB, U17.VDD, U18.VDD, U19.1, U19.5, U20.VDD
ADC_AVDD: C31.1, U1.ADC_AVDD
AS_3V3: TP21.1, U14.B4
AS_N: J1.B18, U14.A4
BOOT_QSPI_CS: U1.QSPI_CS, U9.1
BOOT_QSPI_IO0: U1.QSPI_SD0, U9.5
BOOT_QSPI_IO1: U1.QSPI_SD1, U9.2
BOOT_QSPI_IO2: U1.QSPI_SD2, U9.3
BOOT_QSPI_IO3: U1.QSPI_SD3, U9.7
BOOT_QSPI_SCK: U1.QSPI_SCLK, U9.6
BUS_DISABLE: R14.1, R15.1, R16.1, R17.1, R18.1, TP6.1, U3.OE_N, U4.OE_N, U5.OE_N, U6.OE_N, U8.Y, U14.OE_N, U15.1
CART_5V: C20.1, D1.1, F1.2, R19.2, R20.2, R21.2, R22.2, SW2.6, TP1.1, U3.VCCA, U4.VCCA, U5.VCCA, U6.VCCA, U7.VCCA, U8.VCC, U14.VCCA, U15.8, U16.5, U19.6
CART_5V_IN: F1.1, J1.A2, J1.A31
CART_A0: U3.B1, U13.CART_A0, U17.A0, U18.A0, U20.A0
CART_A1: U3.B2, U13.CART_A1, U17.A1, U18.A1, U20.A1
CART_A2: U3.B3, U13.CART_A2, U17.A2, U18.A2, U20.A2
CART_A3: U3.B4, U13.CART_A3, U17.A3, U18.A3, U20.A3
CART_A4: U3.B5, U13.CART_A4, U17.A4, U18.A4, U20.A4
CART_A5: U3.B6, U13.CART_A5, U17.A5, U18.A5, U20.A5
CART_A6: U3.B7, U13.CART_A6, U17.A6, U18.A6, U20.A6
CART_A7: U3.B8, U13.CART_A7, U17.A7, U18.A7, U20.A7
CART_A8: U4.B1, U13.CART_A8, U17.A8, U18.A8, U20.A8
CART_A9: U4.B2, U13.CART_A9, U17.A9, U18.A9, U20.A9
CART_A10: U4.B3, U13.CART_A10, U17.A10, U18.A10, U20.A10
CART_A11: U4.B4, U13.CART_A11, U17.A11, U18.A11, U20.A11
CART_A12: U4.B5, U13.CART_A12, U17.A12, U18.A12, U20.A12
CART_A13: U4.B6, U13.CART_A13
CART_A14: U4.B7, U13.CART_A14
CART_A15: U4.B8, U13.CART_A15
CART_A16: U5.B1, U13.CART_A16
CART_A17: U5.B2, U13.CART_A17
CART_A18: U5.B3, U13.CART_A18
CART_A19: U5.B4, U13.CART_A19
CART_A20: U5.B5, U13.CART_A20
CART_N: J1.B32, R13.1
CAS0_3V3: U5.B7, U13.CAS0_N
CAS0_N: J1.B16, U5.A7
CAS2_3V3: U5.B8, U13.CAS2_N
CAS2_N: J1.B21, U5.A8
CC1: J2.A5, R1.1
CC2: J2.B5, R2.1
CE0_3V3: U5.B6, U13.CE0_N
CE0_N: J1.B17, U5.A6
CPLD_TCK: J4.4, U13.TCK
CPLD_TDI: J4.8, U13.TDI
CPLD_TDO: J4.6, U13.TDO
CPLD_TMS: J4.2, U13.TMS
DATA_HIGH_BASE_DISABLE: U15.3, U15.6
DATA_HIGH_DISABLE: U7.OE_N, U15.5
FRAM_A13: R42.1, U13.FRAM_A13, U17.A13, U18.A13
FRAM_A14: R33.1, U13.FRAM_A14, U17.A14, U18.A14
FRAM_CE_N: R34.1, TP13.1, U13.FRAM_CE_N, U17.CE_N
FRAM_HI_CE_N: R43.1, TP14.1, U13.FRAM_HI_CE_N, U18.CE_N
FRAM_OE_N: R35.1, TP15.1, U13.FRAM_OE_N, U17.OE_N, U18.OE_N, U20.OE_N
FRAM_WE_N: R36.1, TP16.1, U13.FRAM_WE_N, U17.WE_N, U18.WE_N, U20.WE_N
GND: C1.2, C2.2, C3.2, C4.2, C5.2, C6.2, C7.2, C8.2, C9.2, C10.2, C11.2, C12.2, C13.2, C14.2, C15.2, C16.2, C17.2, C18.2, C19.2, C20.2, C21.2, C22.2, C23.2, C24.2, C25.2, C26.2, C27.2, C28.2, C29.2, C30.2, C31.2, C32.2, C33.2, C34.2, C35.2, C36.2, D3.2, D4.2, D5.2, J1.A1, J1.A18, J1.A32, J2.A1, J2.A12, J2.B1, J2.B12, J2.S1, J3.3, J3.5, J3.9, J4.3, J4.5, J4.9, Q1.2, Q2.2, Q3.2, Q4.2, R1.2, R2.2, R6.2, R8.2, R13.2, R14.2, R15.2, R16.2, R17.2, R18.2, R23.2, R30.2, R33.2, R37.2, R38.2, R39.2, R40.2, R41.2, R42.2, R44.2, SW1.2, SW2.1, SW2.4, SW4.1, TP5.1, U1.EP, U1.GND_1, U1.GND_2, U2.GND, U3.GND, U4.GND, U5.GND, U6.GND, U7.GND, U8.GND, U9.4, U10.4, U11.2, U12.GND, U13.GND_1, U13.GND_2, U14.A6, U14.A7, U14.A8, U14.GND, U15.4, U16.2, U17.VSS, U18.VSS, U19.3, U20.A13, U20.A14, U20.VSS
LED_AMBER: R10.1, U1.GPIO46
LED_AMBER_A: D4.1, R10.2
LED_GREEN: R9.1, U1.GPIO45
LED_GREEN_A: D3.1, R9.2
LED_RED: R11.1, U1.GPIO47
LED_RED_A: D5.1, R11.2
LOW_DATA_DIR: U6.DIR, U16.4
LWR_3V3: TP19.1, U13.LWR_N, U14.B1
LWR_N: J1.B28, U14.A1, U16.1
M3_N: J1.B30, Q1.3
MD_FRAM_CE_N: R45.1, TP17.1, U13.MD_FRAM_CE_N, U20.CE_N
MD_HIGH_DISABLE_3V3: TP18.1, U13.MD_HIGH_DISABLE, U19.2
MD_HIGH_DISABLE_5V: U15.7, U19.4
MEM_D0: U1.GPIO21, U2.DQ0, U6.B1, U13.DATA_IN0, U17.DQ0, U18.DQ0, U20.DQ0
MEM_D1: U1.GPIO22, U2.DQ1, U6.B2, U13.DATA_IN1, U17.DQ1, U18.DQ1, U20.DQ1
MEM_D2: U1.GPIO23, U2.DQ2, U6.B3, U13.DATA_IN2, U17.DQ2, U18.DQ2, U20.DQ2
MEM_D3: U1.GPIO24, U2.DQ3, U6.B4, U13.DATA_IN3, U17.DQ3, U18.DQ3, U20.DQ3
MEM_D4: U1.GPIO25, U2.DQ4, U6.B5, U13.DATA_IN4, U17.DQ4, U18.DQ4, U20.DQ4
MEM_D5: U1.GPIO26, U2.DQ5, U6.B6, U13.DATA_IN5, U17.DQ5, U18.DQ5, U20.DQ5
MEM_D6: U1.GPIO27, U2.DQ6, U6.B7, U13.DATA_IN6, U17.DQ6, U18.DQ6, U20.DQ6
MEM_D7: U1.GPIO28, U2.DQ7, U6.B8, U13.DATA_IN7, U17.DQ7, U18.DQ7, U20.DQ7
MEM_D8: U1.GPIO29, U2.DQ8, U7.B1
MEM_D9: U1.GPIO30, U2.DQ9, U7.B2
MEM_D10: U1.GPIO31, U2.DQ10, U7.B3
MEM_D11: U1.GPIO32, U2.DQ11, U7.B4
MEM_D12: U1.GPIO33, U2.DQ12, U7.B5
MEM_D13: U1.GPIO34, U2.DQ13, U7.B6
MEM_D14: U1.GPIO35, U2.DQ14, U7.B7
MEM_D15: U1.GPIO36, U2.DQ15, U7.B8
MRES_3V3: R41.1, U13.RESET_N, U14.B2
MRES_N: J1.B2, U14.A2
PAUSE_GATE: Q4.1, R40.1, SW3.2
ROM_A0: U1.GPIO0, U2.A0, U13.ROM_A0
ROM_A1: U1.GPIO1, U2.A1, U13.ROM_A1
ROM_A2: U1.GPIO2, U2.A2, U13.ROM_A2
ROM_A3: U1.GPIO3, U2.A3, U13.ROM_A3
ROM_A4: U1.GPIO4, U2.A4, U13.ROM_A4
ROM_A5: U1.GPIO5, U2.A5, U13.ROM_A5
ROM_A6: U1.GPIO6, U2.A6, U13.ROM_A6
ROM_A7: U1.GPIO7, U2.A7, U13.ROM_A7
ROM_A8: U1.GPIO8, U2.A8, U13.ROM_A8
ROM_A9: U1.GPIO9, U2.A9, U13.ROM_A9
ROM_A10: U1.GPIO10, U2.A10, U13.ROM_A10
ROM_A11: U1.GPIO11, U2.A11, U13.ROM_A11
ROM_A12: U1.GPIO12, U2.A12, U13.ROM_A12
ROM_A13: U1.GPIO13, U2.A13, U13.ROM_A13
ROM_A14: U1.GPIO14, U2.A14, U13.ROM_A14
ROM_A15: U1.GPIO15, U2.A15, U13.ROM_A15
ROM_A16: U1.GPIO16, U2.A16, U13.ROM_A16
ROM_A17: U1.GPIO17, U2.A17, U13.ROM_A17
ROM_A18: U1.GPIO18, U2.A18, U13.ROM_A18
ROM_A19: U1.GPIO19, U2.A19, U13.ROM_A19
ROM_A20: U1.GPIO20, U2.A20, U13.ROM_A20
ROM_BYTE_N: R27.1, U2.BYTE_N
ROM_CE_N: R31.1, TP10.1, U1.GPIO37, U2.CE_N, U13.ROM_CE_N
ROM_OE_N: R32.1, TP11.1, U1.GPIO38, U2.OE_N, U13.ROM_OE_N
ROM_RESET_N: R25.1, U2.RESET_N
ROM_WE_N: R12.1, TP12.1, U1.GPIO39, U2.WE_N
ROM_WP_N: R26.1, U2.WP_N
RUN_N: J3.6, U1.RUN
SMS_MAPPER_CM_3V3: R44.1, SW4.2, U13.CODEMASTERS
SMS_MODE_3V3: Q1.1, Q2.1, Q3.1, R37.1, R38.1, R39.1, SW2.2, SW3.1, TP7.1, U13.SMS_MODE
SMS_MODE_5V: SW2.5, TP8.1, U15.2
STAGE_CS_N: U1.GPIO41, U10.1
STAGE_MISO: U1.GPIO40, U10.2
STAGE_MOSI: U1.GPIO43, U10.5
STAGE_SCK: U1.GPIO42, U10.6
SWCLK: J3.4, U1.SWCLK
SWDIO: J3.2, U1.SWDIO
SYS_5V: C23.1, D1.2, D2.2, TP3.1, U11.1, U11.3
TIME_3V3: TP22.1, U14.B5
TIME_N: J1.B31, U14.A5
U3_DIR: R19.1, U3.DIR
U4_DIR: R20.1, U4.DIR
U5_DIR: R21.1, U5.DIR
U7_DIR: R23.1, U7.DIR
U14_DIR: R22.1, U14.DIR
UART_RX: J3.10, U1.UART_RX
UART_TX: J3.8, U1.UART_TX
USB_DM: J2.A7, J2.B7, R4.1, U12.IO2A
USB_DM_MCU: R4.2, U1.USB_DM, U12.IO2B
USB_DP: J2.A6, J2.B6, R3.1, U12.IO1A
USB_DP_MCU: R3.2, U1.USB_DP, U12.IO1B
USB_MODE_3V3: R29.2, R30.1, TP9.1, U13.USB_MODE
USB_PRESENT: R5.2, R6.1, U8.A
USB_SENSE_PROGRAM: R7.2, R8.1, SW1.1, U1.GPIO44
USB_VBUS: D2.1, J2.A4, J2.A9, J2.B4, J2.B9, R5.1, R7.1, R29.1, TP2.1
UWR_3V3: TP20.1, U14.B3
UWR_N: J1.B29, U14.A3
VA1: J1.A17, U3.A1
VA2: J1.A15, U3.A2
VA3: J1.A13, U3.A3
VA4: J1.A11, U3.A4
VA5: J1.A9, U3.A5
VA6: J1.A7, U3.A6
VA7: J1.A5, U3.A7
VA8: J1.A3, U3.A8
VA9: J1.B4, U4.A1
VA10: J1.B5, U4.A2
VA11: J1.A4, U4.A3
VA12: J1.A6, U4.A4
VA13: J1.A8, U4.A5
VA14: J1.A10, U4.A6
VA15: J1.A12, U4.A7
VA16: J1.A14, U4.A8
VA17: J1.A16, U5.A1
VA18: J1.B6, U5.A2
VA19: J1.B7, U5.A3
VA20: J1.B8, U5.A4
VA21: J1.B9, Q2.3, U5.A5
VA22: J1.B10, Q3.3
VA23_PAUSE: J1.B11, Q4.3
VD0: J1.A20, U6.A1
VD1: J1.A23, U6.A2
VD2: J1.A26, U6.A3
VD3: J1.A29, U6.A4
VD4: J1.A28, U6.A5
VD5: J1.A25, U6.A6
VD6: J1.A22, U6.A7
VD7: J1.A19, U6.A8
VD8: J1.A21, U7.A1
VD9: J1.A24, U7.A2
VD10: J1.A27, U7.A3
VD11: J1.A30, U7.A4
VD12: J1.B25, U7.A5
VD13: J1.B24, U7.A6
VD14: J1.B23, U7.A7
VD15: J1.B22, U7.A8
VREG_AVDD: C30.1, R24.2, U1.VREG_AVDD
VREG_SW: L1.1, U1.VREG_SW
XIN: R28.2, U1.XIN
XIN_XTAL: C25.1, R28.1, Y1.1
XOUT: C26.1, U1.XOUT, Y1.2

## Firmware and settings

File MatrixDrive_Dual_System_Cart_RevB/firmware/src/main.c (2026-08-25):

/* SPDX-License-Identifier: MIT */
#include "board_pins.h"
#include "fat16.h"
#include "msc_disk.h"
#include "parallel_nor.h"
#include "rom_installer.h"
#include "spi_nor.h"
#include "status.h"
#include "hardware/adc.h"
#include "pico/stdlib.h"
#include "tusb.h"

#define USB_PRESENT_ADC_MIN 1800u
#define BUTTON_ADC_MAX       500u

static uint16_t sense_read(void) {
    adc_select_input(ADC_USB_PROGRAM_CH);
    return adc_read();
}

static bool button_edge(void) {
    static bool was_down;
    static absolute_time_t changed;
    const bool down = sense_read() < BUTTON_ADC_MAX && tud_mounted();
    const bool stable = absolute_time_diff_us(changed, get_absolute_time()) > 30000;
    bool pressed = false;
    if (down != was_down && stable) {
        was_down = down;
        changed = get_absolute_time();
        pressed = down;
    }
    return pressed;
}

static void show_install_result(install_result_t result) {
    if (result == INSTALL_OK) status_set(STATUS_SUCCESS);
    else if (result == INSTALL_NO_IMAGE || result == INSTALL_BAD_IMAGE)
        status_set(STATUS_BAD_IMAGE);
    else status_set(STATUS_FLASH_ERROR);
}

int main(void) {
    parallel_nor_console_safe_state();
    status_init();
    adc_init();
    adc_gpio_init(PIN_USB_PROGRAM_ADC);
    sleep_ms(2u);

    /* Console mode needs no MCU intervention: the CPLD feeds active NOR/FRAM. */
    if (sense_read() < USB_PRESENT_ADC_MIN) {
        while (true) {
            status_task();
            tight_loop_contents();
        }
    }

    if (!storage_init() || !fat16_format_if_needed()) {
        status_set(STATUS_FLASH_ERROR);
        while (true) status_task();
    }

    tusb_init();
    while (true) {
        tud_task();
        status_task();

        if (button_edge() && !msc_request_manual_install())
            status_set(STATUS_FLASH_ERROR);

        if (msc_take_install_request())
            show_install_result(rom_install_from_staging());
    }
}

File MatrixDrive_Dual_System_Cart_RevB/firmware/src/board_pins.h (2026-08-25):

/* SPDX-License-Identifier: MIT */
#pragma once

/* Parallel active-ROM bus: GPIO0..20 address, GPIO21..36 data. */
#define PIN_ROM_A_FIRST       0u
#define PIN_ROM_A_COUNT      21u
#define PIN_ROM_D_FIRST      21u
#define PIN_ROM_D_COUNT      16u
#define PIN_ROM_CE_N         37u
#define PIN_ROM_OE_N         38u
#define PIN_ROM_WE_N         39u

/* Dedicated SPI1 staging flash on the valid RP2350B GPIO40..43 group. */
#define PIN_STAGE_MISO       40u
#define PIN_STAGE_CS_N       41u
#define PIN_STAGE_SCK        42u
#define PIN_STAGE_MOSI       43u

/* GPIO44/ADC4 sits at about VBUS/2. SW1 pulls it low. */
#define PIN_USB_PROGRAM_ADC  44u
#define ADC_USB_PROGRAM_CH    4u
#define PIN_LED_GREEN        45u
#define PIN_LED_AMBER        46u
#define PIN_LED_RED          47u

#define STAGE_FLASH_BYTES    (16u * 1024u * 1024u)
#define MSC_BLOCK_BYTES      512u
#define MSC_BLOCK_COUNT      (STAGE_FLASH_BYTES / MSC_BLOCK_BYTES)
#define ACTIVE_ROM_BYTES     (4u * 1024u * 1024u)
#define ACTIVE_SMS_BYTES     (2u * 1024u * 1024u)

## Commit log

2026-08-25 Unpack MatrixDrive project source [skip ci]
    [MatrixDrive-RevB.kicad_pcb, bom.csv, connector-pinout.csv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]
2026-08-25 Add Codemasters SMS mapper and 64 KiB FRAM
    [bom.csv, electrical-netlist.csv]
2026-08-25 Add Codemasters SMS mapper and 64 KiB FRAM
    Adds SW4 Sega/Codemasters selection, exact Codemasters banking and RAM decode, two-chip 64 KiB FRAM, updated hardware documentation, RTL tests, and rebuilt RP2350B firmware package.
    [MatrixDrive-RevB.kicad_pcb, bom.csv, electrical-netlist.csv]
2026-08-25 Add Sonic & Knuckles lock-on compatibility
    Adds lock-on ROM mirroring, optional Sonic 3 save FRAM decode, upper-byte isolation, updated hardware documentation, expanded tests, and the rebuilt project package. Public documentation and package 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
    [MatrixDrive-RevB.kicad_pcb, bom.csv, connector-pinout.csv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]
2026-08-25 Add real 32X cartridge ROM support
    [MatrixDrive-RevB.kicad_pcb]
2026-08-25 Regenerate MatrixDrive PCB template and package [skip ci]
2026-08-27 Add experimental MegaCD FPGA ODE architecture
    [bom.csv, connector-pinout.csv, electrical-netlist.csv]
2026-08-27 Add FPGA YM2413 support for Master System mode
    [connector-pinout.csv, electrical-netlist.csv, fpga-addon-bom.csv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]
2026-08-28 Add complete MatrixDrive KiCad project
    [MatrixDrive-RevB.kicad_pcb, MatrixDrive-RevB.sch]
2026-08-28 Clarify KiCad workflow regeneration
2026-08-28 Regenerate MatrixDrive KiCad project and packages [skip ci]
2026-08-28 Route MatrixDrive PCB for KiCad DRC
    [MatrixDrive-RevB.kicad_pcb]
